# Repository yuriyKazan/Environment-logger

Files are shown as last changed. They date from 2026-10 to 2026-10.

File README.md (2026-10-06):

# Environment Logger

An autonomous ESP32-S3 telemetry logger: it reads temperature, humidity and pressure from a BME280 every 5 seconds, stamps each reading with a DS3231 real-time clock, 
prints a formatted line over UART, publishes the values over MQTT, and keeps running when the I2C bus misbehaves or a task hangs.

```
[14:18:54] T:24.3 H:40% P:983 ERR:0
```

> Author: **Yurii Kazan** · Course final project, Embedded Development · Firmware: C++ on ESP-IDF 5.5.3 + FreeRTOS

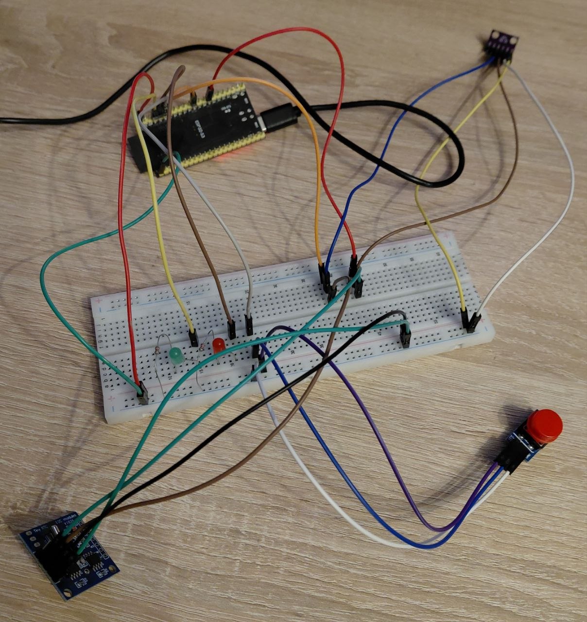
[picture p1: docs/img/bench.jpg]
Test bench


## Table of contents

1. [Project description](#1-project-description)
2. [Features](#2-features)
3. [Hardware and wiring](#3-hardware-and-wiring)
4. [Why these components](#4-why-these-components)
5. [Architecture](#5-architecture)
6. [Interfaces](#6-interfaces)
7. [Log format](#7-log-format)
8. [MQTT telemetry](#8-mqtt-telemetry)
9. [Error strategy](#9-error-strategy)
10. [How to build and run](#10-how-to-build-and-run)
11. [Results](#11-results)
12. [Testing](#12-testing)
13. [Known issues and limitations](#13-known-issues-and-limitations)
14. [What I would improve](#14-what-i-would-improve)
15. [Self-check against the checklist](#15-self-check-against-the-checklist)
16. [Technology stack, credits and license](#16-technology-stack-credits-and-license)

## 1. Project description

**Problem.** A logger that sits unattended must keep producing trustworthy data. The usual failure modes are quiet ones: a loose wire makes the I2C bus hang, a task 
deadlocks, the clock battery dies and every record is stamped `2000-01-01`. A logger that stops without telling anyone is worse than no logger.

**Solution.** The firmware is split into independent FreeRTOS tasks (sensor, UART output, supervisor, MQTT). The measurement is an event-driven state machine with 
bounded retries, every wait has a timeout, the I2C bus is protected by one mutex, and a task watchdog resets the chip if a task stops running. After a reset the 
firmware reports why it restarted.

**Use cases.** Room or lab climate logging, a data source for a dashboard, and a small reference for building recoverable I2C firmware on ESP-IDF.

## 2. Features

- BME280 readings (temperature, humidity, pressure) every 5 s, filtered with an EMA (`alpha` = 0.2).
- Timestamps from a DS3231 RTC; an invalid RTC (dead battery, default date) is detected and the entry is marked `!TIME`.
- Formatted log line over UART0 at 115200 baud, written by a single task.
- Best-effort MQTT publishing over Wi-Fi to a public broker; the logger works without a network.
- I2C error handling: three attempts 100 ms apart, then a bus reset requested from the supervisor, then the next cycle starts normally.
- Task watchdog (10 s, resets the chip) on the three tasks that keep the logger alive; the reset reason is logged at boot.
- No `delay()`, no `vTaskDelay()`, no busy-wait: pauses are states of a state machine, ended by events or one-shot timers.
- Two LEDs (OK heartbeat, error) and a button (short press clears the error counter, long press demonstrates the watchdog).
- A diagnostics task that periodically reports heap, CPU load and per-task stack use.
- Unit tests for the pure logic, run on the PC.

## 3. Hardware and wiring

Board: ESP32-S3-DevKitM-1, powered over USB.

| Part | Role | Interface | Address / pin |
|---|---|---|---|
| BME280 module | Temperature, humidity, pressure | I2C | `0x76` |
| DS3231 module (with CR2032) | Real-time clock | I2C, same bus | `0x68` (its EEPROM answers at `0x50`, unused) |
| LED_OK + 220 Ω | Heartbeat: T3 is alive | GPIO out | GPIO4 |
| LED_ERR + 220 Ω | Error / recovery in progress | GPIO out | GPIO5 |
| Button module (3 pins) | Operator input | GPIO in + interrupt | GPIO6, pressed = high |
| UART0 | Log output | UART | TX GPIO43, RX GPIO44, 115200 8N1 |

I2C: SDA = GPIO8, SCL = GPIO9, 400 kHz. The pull-ups are on the modules (BME280 10 kΩ, DS3231 4.7 kΩ per line, about 3.2 kΩ in parallel), so no external resistors are used.

```
ESP32-S3                BME280 (0x76)         DS3231 (0x68)
3V3  ------------------ VCC ----------------- VCC
GND  ------------------ GND ----------------- GND
GPIO8 (SDA) ------------ SDA ----------------- SDA
GPIO9 (SCL) ------------ SCL ----------------- SCL

GPIO4 --[220R]--|>|-- GND   (LED_OK)
GPIO5 --[220R]--|>|-- GND   (LED_ERR)
GPIO6 ------------------ OUT  (button module: VCC to 3V3, GND to GND, pressed = high)
```

Schematic: [`docs/schematic/schematic.png`](docs/schematic/schematic.png) ([PDF](docs/schematic/schematic.pdf)), KiCad sources in [`hardware/kicad/`](hardware/kicad/). 
More wiring notes: [`docs/hardware.md`](docs/hardware.md).

Notes:

- The DS3231 module has a charging circuit meant for a rechargeable LIR2032. This build uses a non-rechargeable CR2032, which is acceptable for a short demo; for long unattended use fit an LIR2032 or disable the charging circuit on the module.
- Wi-Fi: the ESP32-S3 supports **2.4 GHz networks only**.

## 4. Why these components

Each element answers one need of the project; nothing was added only to tick a checklist line.

| Element | Need it covers |
|---|---|
| BME280 | The measured quantities themselves, three in one chip on one I2C address |
| DS3231 | A log without a trustworthy time is hard to use; the DS3231 keeps time across power loss and flags a lost oscillator |
| One I2C bus for both | Two devices, two wires, one mutex; a second bus would add pins and no benefit |
| LED_OK / LED_ERR | The state of the logger is visible without a terminal |
| Button | A way to clear the error counter and to trigger the watchdog demonstration on demand |
| Wi-Fi + MQTT | Remote access to the readings; best effort, so it cannot endanger the logging |
| Task WDT | A hung task must end in a restart, not in silence |

Deliberately **not** included, with the reasons:

- **Photoresistor / ADC (checklist 2.1):** a temperature, humidity and pressure logger has no organic need for light measurement. It was in the original brief; I dropped it after discussing it with the instructor, because adding a sensor only to cover a checklist item would make the design less coherent. The log format therefore has no `LUX` field.
- **Light Sleep:** the board is powered over USB, so saving energy has no practical meaning here, and Light Sleep conflicts with the continuous Wi-Fi/MQTT link and with the UART log. See [`docs/decisions.md`](docs/decisions.md), item 10.
- **DMA:** one cycle moves about 20 bytes over I2C and the bus is busy 0.035 % of the time; measured, DMA would gain nothing ([`docs/measurements.md`](docs/measurements.md)).
- **Checklist 6.2 and 7.2-7.7:** not applicable to this design; the reason for each item is in [`docs/self-check.md`](docs/self-check.md) (summary in [section 15](#15-self-check-against-the-checklist) of this README).

## 5. Architecture

### Layers

| Layer | Responsibility | Contents |
|---|---|---|
| **Periph** | Hardware init and raw access | `I2cBus`, `Bme280`, `Ds3231`, `Led`, `Button`, `WifiManager` |
| **Logic** | Data processing | `SensorTask` (T1), `Ema`, `sensor_validation`, `TimeSource`, `LogEntry`, `format_log_line` |
| **Transport / Output** | Emitting data | `UartLogTask` (T2), `MqttPublisher`, `MqttTask` (T4) |
| **Reliability** | Staying alive | `SupervisorTask` (T3), `I2cMutex`, `ErrorCounter`, watchdog, reset reason, `DiagnosticsTask` |

Source layout: `src/periph`, `src/logic`, `src/transport`, `src/reliability`; shared headers and all constants (`config.h`) in `include/`. Upper layers call lower ones, never the reverse.

### Tasks

| Task | Priority | Responsibility |
|---|---|---|
| **T3 supervisor** | 6 | Bus reset on request, LEDs, button gestures, watchdog feed |
| **T1 sensor** | 5 | Measurement state machine: timer events, BME280 + DS3231 reads under the mutex, retries, validation, EMA, fan-out of the `LogEntry` |
| **T2 uart_log** | 4 | The only writer of log lines |
| **T4 mqtt** | 3 | Publish to the broker, best effort |
| diag | 1 | Periodic heap / CPU / stack snapshot |

Why Tasks and not one loop: the responsibilities are independent and have different timing needs, and a blocking call in one (an I2C transfer, a network publish) must block only that task. Why T4 is separate from T2: a network publish has unpredictable latency and would distort the UART cadence. The supervisor has the highest priority so that a recovery can always run.

### Queues and mutex

An arrow between two tasks is a **Queue**; two code paths reaching one resource need a **Mutex**.

| Queue | From → to | Item | When full |
|---|---|---|---|
| T1 queue | timers, T3 → T1 | `IsrEvent` | event dropped and counted |
| T3 queue | T1, button ISR, timer → T3 | `IsrEvent` | event dropped and logged |
| Q_LOG | T1 → T2 | `LogEntry` | newest entry dropped and counted |
| Q_MQTT | T1 → T4 | `LogEntry` | oldest entry dropped (the broker gets fresh data) |

**One mutex for the whole I2C bus**, not one per device. It is taken with a 200 ms timeout (never `portMAX_DELAY`), held only during a transfer, and always released through an RAII guard (`I2cLockGuard`), also on error paths. There is a single lock, so no lock-ordering problem. ISRs use only `...FromISR` calls.

### Block diagram

```mermaid
flowchart LR
    subgraph HW[Hardware]
        BME[BME280 0x76]
        RTC[DS3231 0x68]
        BTN[Button module GPIO6]
        LEDS[LED_OK / LED_ERR]
        UART[UART0]
        WIFI[Wi-Fi and MQTT broker]
    end
    TMR[esp_timer callbacks] --> Q1[[T1 queue]]
    Q1 --> T1
    subgraph Tasks
        T1[T1 sensor]
        T2[T2 uart_log]
        T3[T3 supervisor]
        T4[T4 mqtt]
    end
    MTX{{I2C_MUTEX}}
    T1 -- take/give --- MTX
    T3 -- take/give --- MTX
    MTX --- BME
    MTX --- RTC
    T1 --> QLOG[[Q_LOG]] --> T2 --> UART
    T1 --> QMQTT[[Q_MQTT]] --> T4 --> WIFI
    T1 -- I2cFailure, MeasurementOk --> Q3[[T3 queue]]
    BTN -- ISR --> Q3
    Q3 --> T3
    T3 -- RecoveryDone, TestHang --> Q1
    T3 --> LEDS
    T1 -. feeds .-> WDT((Task WDT))
    T2 -. feeds .-> WDT
    T3 -. feeds .-> WDT
```

### State machine of T1 (FSM)

```mermaid
stateDiagram-v2
    [*] --> Idle
    Idle --> WaitConversion: Tick, conversion started
    Idle --> WaitRetry: Tick, start failed (attempt below 3)
    WaitConversion --> Idle: read ok and sample plausible
    WaitConversion --> WaitRetry: read failed or sample rejected (attempt below 3)
    WaitConversion --> Recovery: read failed or sample rejected (attempt 3)
    WaitRetry --> WaitConversion: Retry timer, conversion started
    WaitRetry --> WaitRetry: Retry timer, start failed (attempt below 3)
    WaitRetry --> Recovery: Retry timer, start failed (attempt 3)
    Recovery --> Idle: RecoveryDone or RecoveryTimeout, failed cycle logged
```

The 10 ms BME280 conversion wait and the 100 ms retry gap are one-shot `esp_timer`s that post an event to T1's queue; T1 sleeps in `xQueueReceive` meanwhile.

### Sequence diagram: normal cycle

```mermaid
sequenceDiagram
    participant TMR as esp_timer
    participant T1 as T1 sensor
    participant MTX as I2C_MUTEX
    participant BME as BME280
    participant RTC as DS3231
    participant T2 as T2 uart_log
    participant T4 as T4 mqtt
    TMR->>T1: Tick (T1 queue)
    T1->>MTX: take (200 ms)
    T1->>BME: trigger forced conversion
    T1->>MTX: give
    Note over T1: one-shot timer of 10 ms, T1 waits on its queue (no delay)
    TMR->>T1: ConversionDone
    T1->>MTX: take (200 ms)
    T1->>BME: read status and data
    T1->>RTC: read time and status
    T1->>MTX: give
    Note over T1: validate, EMA, resolve the timestamp, build LogEntry
    T1->>T2: Q_LOG (LogEntry)
    T1->>T4: Q_MQTT (LogEntry)
    T2->>T2: format and print the line
    T4->>T4: publish when connected
```

### Sequence diagram: I2C failure and recovery

```mermaid
sequenceDiagram
    participant T1 as T1 sensor
    participant MTX as I2C_MUTEX
    participant BME as BME280
    participant T3 as T3 supervisor
    participant T2 as T2 uart_log
    loop attempts 1 to 3, 100 ms apart (one-shot timer)
        T1->>MTX: take
        T1->>BME: start or read
        BME--xT1: no answer
        T1->>MTX: give
    end
    T1->>T3: I2cFailure (T3 queue)
    Note over T1: state Recovery, waits at most 2 s
    T3->>T3: LED_ERR on, LED_OK off
    T3->>MTX: take (200 ms)
    T3->>T3: i2c_master_bus_reset (clears the bus)
    T3->>MTX: give
    T3-->>T1: RecoveryDone (T1 queue)
    T1->>T2: Q_LOG (ERR + 1, !SENS !TIME)
    Note over T1: next cycle starts normally at the next tick
    T1->>T3: MeasurementOk (when a cycle succeeds again)
    T3->>T3: LED_ERR off, LED_OK blinks again
```

### UML class view

The class diagram (tasks, drivers, mutex, data types and their dependencies) and the watchdog sequence diagram are in section 11 of [`docs/architecture.md`](docs/architecture.md); the rest of that document describes every design choice in full. The design decisions in "I chose X because Y; the alternative was Z" form are in [`docs/decisions.md`](docs/decisions.md).

## 6. Interfaces

| Interface | Configuration | Notes |
|---|---|---|
| **I2C** | `driver/i2c_master.h` (new driver), port 0, SDA 8 / SCL 9, 400 kHz, glitch filter 7 | Device handles at `0x76` and `0x68`; transfers have a 100 ms timeout; `i2c_master_bus_reset()` for recovery. `i2c_master_probe()` always runs at 100 kHz (fixed by ESP-IDF) |
| **UART** | UART0, 115200 8N1, TX 43 / RX 44 | The console; only T2 writes log lines |
| **Timers** | `esp_timer`: 5 s measurement tick, 10 ms conversion, 100 ms retry, 2 s recovery timeout, 3 s long press, 30 s Wi-Fi retry | All one-shot or periodic callbacks that only post events |
| **GPIO / interrupt** | Button any-edge ISR, quiet-time debounce 50 ms | The ISR only calls `xQueueSendFromISR` |
| **Task WDT** | 10 s, panic on timeout, T1 + T2 + T3 subscribed | See section 9 |
| **Wi-Fi / MQTT** | Station mode, `esp-mqtt`, QoS 0 | See section 8 |

All numeric constants (pins, intervals, timeouts, queue lengths, priorities, stack sizes) are in [`include/config.h`](include/config.h).

## 7. Log format

```
[HH:MM:SS] T:23.4 H:48% P:1013 ERR:0
```

- `T` temperature in °C, `H` relative humidity in %, `P` pressure in hPa, all EMA-filtered.
- `ERR` is the number of failed measurement cycles since boot or since the last short button press (saturating counter).
- Markers: ` !TIME` the timestamp does not come from a valid RTC (the internal clock is used); ` !SENS` the values are not from a successful read.

**EMA:** `filtered = alpha * raw + (1 - alpha) * filtered`, `alpha` = 0.2. At a 5 s period this is a time constant of 22 s: a short disturbance is attenuated to about half or two thirds, a single outlier passes with only 20 % of its size, and the filter follows a real change in about a minute. 0.05 reacted to only a quarter of a disturbance and was still 4.3 %RH off two minutes later; 0.5 hardly filtered. The experiment, with its limits, is in [`docs/ema-experiment.md`](docs/ema-experiment.md).

**Validation:** a sample outside the BME280 operating range (-40...85 °C, 0...100 %RH, 300...1100 hPa) or not finite is rejected and counted as a failed attempt; the filter only receives plausible samples. The RTC time is checked (oscillator-stop flag, date not `2000-01-01`, fields in range) before it is used.

Real log excerpts: [`docs/logs/`](docs/logs/).

## 8. MQTT telemetry

- Broker: `broker.hivemq.com` (public, port 1883), QoS 0, no retain.
- Topics: `envlogger/ykazan/temp`, `.../hum`, `.../pres` (published only when the sensor data is valid, so stale values never look fresh) and `.../err` (always).
- Watch it from any machine:

```
mosquitto_sub -h broker.hivemq.com -t "envlogger/ykazan/#" -v
```

- **Security note:** the broker is public and has no authentication. Anyone can read or publish to these topics; the topic prefix only avoids collisions and is not protection. Room climate data is harmless, but do not reuse this setup for anything sensitive.
- The MQTT path is **best effort and outside the I2C + WDT reliability guarantees**: T4 holds no mutex, never touches I2C, is not subscribed to the watchdog, and drops entries when the broker is not connected. During a router outage the UART log kept its 5 s cadence ([`docs/logs/phase3-mqtt.txt`](docs/logs/phase3-mqtt.txt)).
- Wi-Fi reconnect: 5 immediate attempts, then one attempt every 30 s without a limit, so the logger returns to the network when the access point does.

## 9. Error strategy

| Failure | What happens | Evidence |
|---|---|---|
| BME280 does not answer | 3 attempts 100 ms apart, then a bus reset by T3; the failed cycle is logged with `ERR` + 1 and `!SENS !TIME`; LED_ERR on; recovers by itself | [`phase4-i2c-recovery.txt`](docs/logs/phase4-i2c-recovery.txt), [`logic-analyzer.md`](docs/logic-analyzer.md) |
| A task hangs | The watchdog names it and resets the chip; the reset reason is logged after the restart | [`phase4-wdt.txt`](docs/logs/phase4-wdt.txt) |
| RTC time invalid | Internal clock is used, `!TIME` in the log | [`phase3-rtc.txt`](docs/logs/phase3-rtc.txt) |
| Wi-Fi or broker lost | T4 drops entries, UART log unaffected, automatic reconnect | [`phase3-mqtt.txt`](docs/logs/phase3-mqtt.txt) |
| Implausible sensor value | Rejected, counted as a failed attempt | unit tests |
| A consumer stalls (queue full) | Documented drop policy per queue, T1 never blocks | [`phase6-queue-overflow.txt`](docs/logs/phase6-queue-overflow.txt) |

Example of a failed cycle (the SDA wire was pulled out while running):

```
W (65460) T1: BME280 start failed: ESP_ERR_INVALID_STATE (attempt 1/3)
W (65560) T1: BME280 start failed: ESP_ERR_INVALID_STATE (attempt 2/3)
W (65660) T1: BME280 start failed: ESP_ERR_INVALID_STATE (attempt 3/3)
E (65660) T1: I2C failed 3 times in a row: requesting a bus reset
W (65670) T3: bus reset #1: ESP_OK
[17:27:36] T:24.5 H:40% P:982 ERR:1 !TIME !SENS
...
I (95470) T1: sensor is back
```

**Watchdog.** The timeout is 10 s with `CONFIG_ESP_TASK_WDT_PANIC=y`, so a timeout resets the chip and `ESP_RST_TASK_WDT` becomes visible after the restart. The course documents set both the WDT timeout and the measurement interval to 5 s, which would reset the logger on a normal cycle; here the feed is decoupled from the interval (T1 and T2 feed after each 1 s queue wait, T3 after each 0.5 s) and the worst case between two feeds of T1 is about 1.6 s. T4, the diagnostics task and the idle tasks are not subscribed, so a bad network can never reset the logger. Boot log after a watchdog reset:

```
E (26460) task_wdt: The following tasks/users did not reset the watchdog in time:
E (26460) task_wdt:  - T1_sensor (CPU 0)
...
E (405) reset: previous run ended with a WATCHDOG reset (task watchdog): a task hung or deadlocked
```

Defensive-coding review (every wait has a timeout, every retry is bounded, every return value is checked, how each shared object is protected): [`docs/defensive-review.md`](docs/defensive-review.md).

## 10. How to build and run

**Requirements:** PlatformIO (CLI or the VS Code extension), a USB cable, the wired board from section 3. The platform is pinned in `platformio.ini`: `espressif32@6.13.0`, which ships ESP-IDF 5.5.3.

```
git clone <repository URL>
cd Environment-logger

# Wi-Fi and MQTT credentials (git-ignored)
cp include/secrets.h.example include/secrets.h     # then edit SSID, password, broker URI

pio run                          # build
pio run -t upload                # flash
pio device monitor               # 115200 baud, with timestamps and exception decoder
pio test -e native               # unit tests on the PC, no board needed
```

Without Wi-Fi the logger still runs; T4 only reports that it cannot connect. A DS3231 with a dead battery reports `2000-01-01`; to set it once from the build time, enable `RTC_SET_FROM_BUILD_TIME_IF_INVALID` in `config.h`, flash, then disable it again.

**Before a demo, check `include/config.h`:**

- `FAULT_STALL_UART` must be `false`. When it is `true`, T2 deliberately stops printing for 90 s after three entries (this is the queue-overflow test).
- `DIAG_ENABLED` can be set to `false` if the extra snapshot line per minute is not wanted.

**What to see on the board:** LED_OK blinks at 1 Hz (T3 is alive); LED_ERR lights up while a bus failure is being handled. Short button press: `ERR` returns to 0. Long press (3 s): T1 hangs on purpose and the watchdog resets the chip about 10 s later.

## 11. Results

All numbers were measured on the real board (ESP32-S3-DevKitM-1, ESP-IDF 5.5.3, one measurement per 5 s); details in [`docs/measurements.md`](docs/measurements.md).

| Quantity | Value |
|---|---|
| Measurement cycle, tick to published entry | 11.9 / 12.0 / 12.4 ms (min / avg / max over 12 cycles; over 10 h 11.9-13.5 ms, one outlier of 21.6 ms in another run), of which 10 ms is the sensor conversion wait |
| I2C bus busy per cycle | about 1.8 ms of 5000 ms (0.035 %) |
| CPU load | 0.7 % |
| Free heap | 231.5-235.5 KB; lowest ever 226.9 KB after 10 h (230.6 KB at 60 s); free heap shows no downward trend |
| Failed cycle (3 attempts + reset) | about 220 ms, the UART log keeps its 5 s cadence |
| Stack, largest use of a 4096 B stack (10 h minimum of free stack) | `diag`: 2512 B used, 1584 B free; T1: 2300 B used, 1796 B free |
| Longest run | 10 h 18 min without a reset: 7425 log lines, all `ERR:0`, no `!SENS` / `!TIME` ([`phase7-long-run.txt`](docs/logs/phase7-long-run.txt)) |
| Unit tests | 37, all on the PC |

Cross-check with a logic analyzer ([`docs/logic-analyzer.md`](docs/logic-analyzer.md)): the cycles start 4.99974 s apart, the conversion wait on the wire is 10.26 ms, the read phase is 1.27 ms (firmware: 1.23 ms), the scan finds exactly `0x50`, `0x68` and `0x76`, and with SDA disconnected the three attempts are 107.5 ms apart.

The long run also had two MQTT disconnects (10.3 s and 15.2 s), both recovered automatically while the UART log kept running. The raw capture is not committed; the evidence file is produced from it by `tools/summarize_long_run.py` with SSID, IP and MAC replaced.

## 12. Testing

| Scenario | How | Result |
|---|---|---|
| Normal operation | 5+ minute run | `ERR:0`, 5 s cadence ([`phase3-pipeline.txt`](docs/logs/phase3-pipeline.txt)) |
| Long run | 10 h 18 min, nobody touching the board | no reset, `ERR:0` throughout, flat heap ([`phase7-long-run.txt`](docs/logs/phase7-long-run.txt)) |
| I2C failure and recovery | SDA wire pulled out and plugged back | 3 attempts, bus reset, automatic recovery ([`phase4-i2c-recovery.txt`](docs/logs/phase4-i2c-recovery.txt)) |
| Watchdog | Long button press | Chip reset, task named, reset reason logged ([`phase4-wdt.txt`](docs/logs/phase4-wdt.txt)) |
| RTC invalid | DS3231 never set (oscillator-stop flag set) | `!TIME` ([`phase3-rtc.txt`](docs/logs/phase3-rtc.txt)) |
| Button | Short and long presses | ([`phase4-button.txt`](docs/logs/phase4-button.txt)) |
| Wi-Fi / MQTT loss | Router switched off | UART cadence unaffected ([`phase3-mqtt.txt`](docs/logs/phase3-mqtt.txt)) |
| Queue overflow | `FAULT_STALL_UART` | Drops counted, T1 not blocked ([`phase6-queue-overflow.txt`](docs/logs/phase6-queue-overflow.txt)) |
| Pure logic | `pio test -e native` | EMA, error counter, log format, validation, timing statistics |

Logs are excerpts; private data (SSID, IP, MAC) is replaced with placeholders.

## 13. Known issues and limitations

- A button tap shorter than the 50 ms debounce quiet time loses its release event; the long-press timer then counts it as a short press after 3 s.
- A bus reset cannot revive a device that is permanently dead or unpowered; every cycle is then logged as failed until it answers. This applies only to a device that failed after a successful start.
- If the BME280 or DS3231 is missing or does not initialise at power-on, the boot self-check logs an error and `app_main` returns: no tasks start, so there is no retry, no LED_ERR and no watchdog. The board stays silent until it is reset or power-cycled with the device connected.
- The DS3231 charging circuit is meant for a rechargeable LIR2032, but a non-rechargeable CR2032 is fitted (section 3). A non-rechargeable cell should not be charged: fine for a short demo, not for long unattended use.
- The public MQTT broker has no authentication and no delivery guarantee (QoS 0); entries are dropped while disconnected.
- 2.4 GHz Wi-Fi only.
- The SCL pulses of the bus reset were not individually confirmed on the logic analyzer (the decoder merges them into the last NAK frame).
- The long run is one 10-hour capture on USB power in one room; it is not a temperature-cycling or brown-out test.
- `sys_evt` (an ESP-IDF task that runs the Wi-Fi event handler) has only 576 B of stack free; it is the one to watch if more work is added to the Wi-Fi/MQTT callbacks.

## 14. What I would improve

- Authenticated MQTT over TLS with a private broker, plus the minimal static web page (MQTT over WebSockets and Chart.js) as a live dashboard.
- Persist the log (flash or SD card) so that a Wi-Fi outage loses no data.
- Light Sleep or Deep Sleep for a battery-powered version, with the UART and Wi-Fi handled around the sleep.
- A hardware I2C bus-recovery path that can also power-cycle the sensors through a GPIO-switched supply.
- Time synchronisation of the RTC over SNTP when the network is available.
- A soak test across temperature changes and with a deliberately unstable power supply.

## 15. Self-check against the checklist

The course checklist was filled in with a piece of evidence (code, log or measurement) for every ticked item; items that do not fit this project are left unticked with a reason instead of being forced. Current state: **30 of 42 items ticked (71 %)**; the four demonstration items are ticked at the live defence (34 of 42, 81 %), and the other eight (2.1, 6.2, 7.2-7.7) are deliberately not applicable, each with its reason. Details and the "need it covers" column: [`docs/self-check.md`](docs/self-check.md).

## 16. Technology stack, credits and license

- C++17 firmware, ESP-IDF 5.5.3 (`framework = espidf`), FreeRTOS, PlatformIO with `espressif32@6.13.0`; Unity for the unit tests.
- Python (`tools/analyze_i2c.py`, `tools/plot_ema.py`) for the logic-analyzer and EMA analysis; Saleae Logic 2 for the captures; KiCad for the schematic; Mermaid for the diagrams.
- Wi-Fi/MQTT code is reused and adapted from my earlier course project (module5). BME280 and DS3231 drivers are my own, with the BME280 compensation formulas taken from the datasheet.
- Parts of this README were drafted with AI assistance from the project's own documents and logs, and then reviewed and corrected by the author.
- License: [MIT](LICENSE).

**Author:** Yurii Kazan

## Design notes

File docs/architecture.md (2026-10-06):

# Architecture

This document describes the firmware as it is implemented. Every constant mentioned here lives in `include/config.h`. Evidence for the behaviour described (logs, measurements) is linked from the sections below and listed in [`logs/`](logs/).

## 1. Layers

| Layer | Responsibility | Contents |
|---|---|---|
| **Periph** | Hardware init and raw access | `I2cBus`, `Bme280`, `Ds3231`, `Led`, `Button`, `WifiManager` |
| **Logic** | Data processing | `SensorTask` (T1), `Ema`, `sensor_validation`, `TimeSource`, `LogEntry`, `format_log_line` |
| **Transport / Output** | Emitting data | `UartLogTask` (T2), `MqttPublisher`, `MqttTask` (T4) |
| **Reliability** | Staying alive | `SupervisorTask` (T3), `I2cMutex`, `ErrorCounter`, `watchdog.h`, `reset_reason`, `DiagnosticsTask`, `TimingStats` |

Source layout mirrors this: `src/periph`, `src/logic`, `src/transport`, `src/reliability`, shared headers in `include/`. All constants (pins, intervals, timeouts, queue lengths, priorities) are in `include/config.h`; shared data types are in `include/data_types.h`. The code is C++; the pure logic that does not need ESP-IDF (`Ema`, `ErrorCounter`, `TimingStats`, `sensor_validation`, `format_log_line`) is unit-tested on the PC (`pio test -e native`, 37 tests).

Dependency rule: upper layers call lower ones, never the reverse. Tasks live in the layer whose responsibility they implement and are created from `app_main`.

## 2. Tasks (one responsibility per Task)

| Task | Layer | Priority | Responsibility |
|---|---|---|---|
| **T3 supervisor** | Reliability | 6 | Bus reset on request, LED_ERR / LED_OK, button gestures, watchdog feed |
| **T1 sensor** | Periph + Logic | 5 | Measurement state machine: timer events, BME280 + DS3231 reads under the I2C mutex, retries, validation, EMA, `LogEntry` fan-out |
| **T2 uart_log** | Transport | 4 | The only writer of log lines: receive `LogEntry`, format, print |
| **T4 mqtt** | Transport | 3 | Publish `LogEntry` to the MQTT broker, best effort |
| diag | Reliability | 1 | Periodic snapshot of heap, CPU load, per-task stack and state (not subscribed to the watchdog) |

The supervisor has the highest priority so that the recovery can always run, even while T1 is busy. T4 has the lowest application priority: it must never compete with the tasks that keep the logger alive.

Why Tasks and not one loop: the processes are independent, have different timing needs, and a blocking call in one (an I2C transfer, a network publish) must put only that Task into the Blocked state, not the whole system.

Why T4 is separate from T2: a network publish has an unpredictable and much longer latency than a UART write. Calling it from T2 would distort the UART log cadence. T4 holds no mutex, never touches I2C, is not subscribed to the watchdog, and is not part of the I2C + WDT reliability guarantees. The system works without Wi-Fi (see [`logs/phase3-mqtt.txt`](logs/phase3-mqtt.txt)).

## 3. Queues and mutex

Rule of thumb: an arrow between two Tasks is a Queue; two code paths reaching one resource need a Mutex.

| Queue | Producers | Consumer | Item | Length | When full |
|---|---|---|---|---|---|
| **T1 queue** | `esp_timer` callbacks (tick, conversion done, retry, recovery timeout), T3 | T1 | `IsrEvent` | 8 | the event is dropped and counted (T1 is never blocked) |
| **T3 queue** | T1, the button ISR, the long-press timer | T3 | `IsrEvent` | 8 | the event is dropped and logged |
| **Q_LOG** | T1 | T2 | `LogEntry` | 8 | the **newest** entry is dropped and counted |
| **Q_MQTT** | T1 | T4 | `LogEntry` | 4 | the **oldest** entry is dropped, so the broker gets the freshest data |

Events carried by the two event queues (`IsrEventType` in `data_types.h`):

| Queue | Event types |
|---|---|
| T1 queue | `Tick`, `ConversionDone`, `Retry`, `RecoveryDone`, `RecoveryTimeout`, `TestHang` |
| T3 queue | `I2cFailure`, `MeasurementOk`, `Button`, `ButtonRelease`, `LongPressTimeout` |

A FreeRTOS queue has one consumer, so T1's fan-out is two sends (Q_LOG and Q_MQTT) with zero timeout. The overflow policy for Q_LOG was verified with a fault-injection test ([`logs/phase6-queue-overflow.txt`](logs/phase6-queue-overflow.txt)).

**One mutex for the whole I2C bus** (`I2cMutex`, created with `xSemaphoreCreateMutex()` for priority inheritance), not one per device: the BME280 and the DS3231 share the bus, and T1 (reads) and T3 (bus reset) both reach it. It is always taken through `I2cLockGuard`, which gives it back on every exit path.

Rules:

- taken with a finite timeout, `I2C_MUTEX_TIMEOUT_MS` = 200 ms; `portMAX_DELAY` is never used on the mutex;
- held only during an I2C transaction, never across a conversion wait, a retry or a recovery;
- a single lock, so there is no lock-ordering problem and no nested locking;
- ISRs use only `...FromISR` APIs (`xQueueSendFromISR`) and never take a mutex.

The shared state and how each part is protected is listed in [`defensive-review.md`](defensive-review.md).

## 4. No `delay()`, and the state machine of T1

Pauses are states exited by an event, not blocking waits: no `delay`, no `vTaskDelay`, no busy-wait in the logic. Every wait is a queue wait with a finite timeout or a one-shot `esp_timer`.

T1 state machine:

```mermaid
stateDiagram-v2
    [*] --> Idle
    Idle --> WaitConversion: Tick, conversion started
    Idle --> WaitRetry: Tick, start failed (attempt below 3)
    WaitConversion --> Idle: read ok and sample plausible
    WaitConversion --> WaitRetry: read failed or sample rejected (attempt below 3)
    WaitConversion --> Recovery: read failed or sample rejected (attempt 3)
    WaitRetry --> WaitConversion: Retry timer, conversion started
    WaitRetry --> WaitRetry: Retry timer, start failed (attempt below 3)
    WaitRetry --> Recovery: Retry timer, start failed (attempt 3)
    Recovery --> Idle: RecoveryDone or RecoveryTimeout, failed cycle logged
```

- **Idle**: waits for `Tick` (one per `MEASURE_INTERVAL_MS` = 5 s).
- **WaitConversion**: the BME280 forced-mode conversion was started; a one-shot timer of `BME280_CONVERSION_US` = 10 ms posts `ConversionDone`.
- **WaitRetry**: an attempt failed; a one-shot timer of `I2C_RETRY_DELAY_MS` = 100 ms posts `Retry`. At most `I2C_MAX_ATTEMPTS` = 3 attempts per cycle.
- **Recovery**: the three attempts failed. T1 sends `I2cFailure` to T3 and waits for `RecoveryDone`, but not longer than `RECOVERY_TIMEOUT_MS` = 2 s.

A sample counts as an attempt failure in three cases: the I2C transfer fails, the BME280 reports a skipped measurement or a conversion still running, or the compensated values are outside the BME280 operating range (`validate_sample`, see section 6). A cycle that ends in Recovery is not retried again; it is logged as failed (`ERR` + 1, markers `!SENS` and `!TIME`) and the next cycle starts at the next tick. When a later cycle succeeds, T1 sends `MeasurementOk` to T3, which clears the error state.

Bounded retries and bounded waits keep the worst case small: a failed cycle takes about 220 ms and never blocks the UART log ([`logs/phase4-i2c-recovery.txt`](logs/phase4-i2c-recovery.txt)).

## 5. Supervisor, LEDs and the button (T3)

T3 reacts to events and also runs its own heartbeat: its queue wait times out every `SUPERVISOR_TICK_MS` = 500 ms, which toggles LED_OK (a 1 Hz blink shows that T3 is alive) and feeds the watchdog.

| Event or state | What T3 does |
|---|---|
| `I2cFailure` from T1 | LED_ERR on, LED_OK off; takes the I2C mutex (200 ms), calls `I2cBus::reset()`, answers `RecoveryDone` with the result, also when the reset failed |
| `MeasurementOk` from T1 | the sensor is back: LED_ERR off, LED_OK blinks again |
| short button press | clears the error counter (`ERR` in the log goes back to 0) |
| long button press (3 s) | watchdog demonstration: sends `TestHang` to T1, which blocks on purpose |

`I2cBus::reset()` calls `i2c_master_bus_reset()`. In ESP-IDF 5.5.3 this resets the I2C hardware state machine **and** clears the bus (SCL pulses until a slave releases SDA), and the device handles stay valid, so recreating the bus is not needed.

The button is a 3-pin module with an on-board pull-down: low at rest, high when pressed (`BUTTON_PRESSED_LEVEL` = 1). An any-edge ISR applies a quiet-time debounce (an edge counts only after `BUTTON_DEBOUNCE_US` = 50 ms without any edge) and posts `Button` or `ButtonRelease` to the T3 queue. A press starts a one-shot long-press timer (`BUTTON_LONG_PRESS_MS` = 3000 ms); a release before it expires is a short press, and the timer handler checks the pin level too, because a tap shorter than the debounce time loses its release event ([`logs/phase4-button.txt`](logs/phase4-button.txt)).

## 6. Watchdog

| Item | Value |
|---|---|
| Timeout | 10 s, `CONFIG_ESP_TASK_WDT_PANIC=y` (a timeout resets the chip) |
| Measurement interval | 5 s (independent of the timeout) |
| Subscribed tasks | T1, T2, T3 |
| Not subscribed | T4 (network), diag, the idle tasks |
| Feed | at the top of every loop iteration of each subscribed task, i.e. after each queue wait (1 s for T1 and T2, 0.5 s for T3) |

The course documents set both the timeout and the interval to 5 s, which would reset the system on a normal cycle. Here the feed is decoupled from the measurement interval, and the timeout is far longer than the longest legal pause: the worst case between two feeds of T1 is about 1.6 s (see [`defensive-review.md`](defensive-review.md)). A task that blocks anywhere else stops feeding, and the watchdog names it and resets the chip within 10 s ([`logs/phase4-wdt.txt`](logs/phase4-wdt.txt)).

At boot `esp_reset_reason()` is logged first; a watchdog reset is logged as an error; a panic, brownout or CPU lockup reset is logged as a warning; any other reason is logged as info. So a previous hang is visible after the restart.

## 7. Data structures, time and log format

```c
struct LogEntry {
    time_t   ts;         // from the DS3231 when valid, else the internal clock
    float    temp_c;     // EMA-filtered
    float    hum_pct;    // EMA-filtered
    float    press_hpa;  // EMA-filtered
    uint32_t err_cnt;    // failed measurement cycles, saturating
    uint8_t  flags;      // LOG_FLAG_SENSOR_VALID, LOG_FLAG_TIME_TRUSTED
};
```

Log line: `[HH:MM:SS] T:23.4 H:48% P:1013 ERR:0`, with two markers when needed: ` !TIME` (the timestamp does not come from a valid RTC) and ` !SENS` (the sensor values are not from a successful read). The `LUX` field of the assignment brief is absent because the photoresistor was dropped (see [`decisions.md`](decisions.md)).

**EMA filter:** `filtered = alpha * raw + (1 - alpha) * filtered`, `alpha` = 0.2. The choice is justified with real data in [`ema-experiment.md`](ema-experiment.md). The filter only receives samples that passed the plausibility check.

**Validation:** a sample is rejected, and counted as a failed attempt, when a value is not finite or outside the BME280 operating range (-40...85 C, 0...100 %RH, 300...1100 hPa).

**Time:** `TimeSource` synchronises the system clock from the DS3231 at boot. For every entry T1 reads the DS3231 under the same mutex as the BME280; a valid reading (oscillator-stop flag clear, date not the default 2000-01-01, fields in range) gives the timestamp. Otherwise the internal clock is used and the entry is marked `!TIME` ([`logs/phase3-rtc.txt`](logs/phase3-rtc.txt)).

**Error counter:** `ErrorCounter` is atomic and saturating (it stops at its maximum instead of wrapping to 0). T1 increments it once per failed cycle; a short button press resets it.

## 8. MQTT telemetry (T4)

- Topics: `envlogger/ykazan/temp`, `/hum`, `/pres` (only when the sensor data is valid, so stale values are never published as fresh) and `/err` (always); public broker `broker.hivemq.com`, QoS 0, no retain.
- A public broker means anyone can read or write the topics. Room climate data is harmless and the prefix is a uniqueness aid, not protection. This is a known limitation, listed in the README.
- T4 never blocks anything: when the broker is not connected the entries are dropped.
- Wi-Fi: `WifiManager` retries immediately 5 times after a drop, then once every 30 s (one-shot timer), without a limit, so the logger reconnects when the access point returns. The ESP32-S3 supports 2.4 GHz networks only. Credentials and the broker URI are in git-ignored `include/secrets.h` (template: `secrets.h.example`).
- Evidence: values received by an independent client, and a router outage during which the UART log kept its 5 s cadence ([`logs/phase3-mqtt.txt`](logs/phase3-mqtt.txt)).

## 9. Boot sequence

`app_main` runs, in this order: log the reset reason; create the I2C bus and scan it; initialise the BME280 and DS3231 and read the RTC state; synchronise the clock (`TimeSource`); create the mutex, the queues, the LEDs; start T2, then T1 (which creates its queue and timers), then T3 (given T1's queue), then attach the button ISR to the T3 queue; start the diagnostics task; last, best effort, NVS, Wi-Fi and MQTT. If the network part fails, the UART log keeps running.

## 10. Block diagram

```mermaid
flowchart LR
    subgraph HW[Hardware]
        BME[BME280 0x76]
        RTC[DS3231 0x68]
        BTN[Button module GPIO6]
        LEDS[LED_OK / LED_ERR]
        UART[UART0]
        WIFI[Wi-Fi and MQTT broker]
    end
    TMR[esp_timer callbacks] --> Q1[[T1 queue]]
    Q1 --> T1
    subgraph Tasks
        T1[T1 sensor]
        T2[T2 uart_log]
        T3[T3 supervisor]
        T4[T4 mqtt]
    end
    MTX{{I2C_MUTEX}}
    T1 -- take/give --- MTX
    T3 -- take/give --- MTX
    MTX --- BME
    MTX --- RTC
    T1 --> QLOG[[Q_LOG]] --> T2 --> UART
    T1 --> QMQTT[[Q_MQTT]] --> T4 --> WIFI
    T1 -- I2cFailure, MeasurementOk --> Q3[[T3 queue]]
    BTN -- ISR --> Q3
    Q3 --> T3
    T3 -- RecoveryDone, TestHang --> Q1
    T3 --> LEDS
    T1 -. feeds .-> WDT((Task WDT))
    T2 -. feeds .-> WDT
    T3 -. feeds .-> WDT
```

## 11. UML

### Class view

```mermaid
classDiagram
    class SensorTask { +start() }
    class SupervisorTask { +start() }
    class UartLogTask { +start() }
    class MqttTask { +start() }
    class DiagnosticsTask { +start() }
    class Bme280 { +init() +start_measurement() +read() }
    class Ds3231 { +init() +read() +set_time() }
    class I2cBus { +init() +reset() +probe() +scan() }
    class I2cMutex { +take(timeout) +give() }
    class I2cLockGuard
    class Led { +set() +toggle() }
    class Button { +init() +is_pressed() }
    class WifiManager { +init() +connected() }
    class MqttPublisher { +init() +start() +publish() }
    class Ema { +update(raw) }
    class TimeSource { +init() +resolve() }
    class ErrorCounter { +increment() +reset() +value() }
    class TimingStats { +add() +avg() }
    class LogEntry {
        +time_t ts
        +float temp_c
        +float hum_pct
        +float press_hpa
        +uint32_t err_cnt
        +uint8_t flags
    }
    SensorTask --> Bme280
    SensorTask --> Ds3231
    SensorTask --> Ema
    SensorTask --> TimeSource
    SensorTask --> ErrorCounter
    SensorTask --> TimingStats
    SensorTask --> I2cLockGuard
    SensorTask --> LogEntry : produces
    I2cLockGuard --> I2cMutex
    Bme280 --> I2cBus
    Ds3231 --> I2cBus
    SupervisorTask --> I2cBus : reset
    SupervisorTask --> I2cMutex
    SupervisorTask --> Led
    SupervisorTask --> Button
    SupervisorTask --> ErrorCounter
    UartLogTask --> LogEntry : consumes
    MqttTask --> MqttPublisher
    MqttTask --> LogEntry : consumes
    MqttPublisher --> WifiManager : started on IP
```

### Sequence 1: normal measurement cycle

```mermaid
sequenceDiagram
    participant TMR as esp_timer
    participant T1 as T1 sensor
    participant MTX as I2C_MUTEX
    participant BME as BME280
    participant RTC as DS3231
    participant T2 as T2 uart_log
    participant T4 as T4 mqtt
    TMR->>T1: Tick (T1 queue)
    T1->>MTX: take (200 ms)
    T1->>BME: trigger forced conversion
    T1->>MTX: give
    Note over T1: one-shot timer of 10 ms, T1 waits on its queue (no delay)
    TMR->>T1: ConversionDone
    T1->>MTX: take (200 ms)
    T1->>BME: read status and data
    T1->>RTC: read time and status
    T1->>MTX: give
    Note over T1: validate, EMA, resolve the timestamp, build LogEntry
    T1->>T2: Q_LOG (LogEntry)
    T1->>T4: Q_MQTT (LogEntry)
    T2->>T2: format and print the line
    T4->>T4: publish when connected
```

### Sequence 2: I2C failure and recovery

```mermaid
sequenceDiagram
    participant T1 as T1 sensor
    participant MTX as I2C_MUTEX
    participant BME as BME280
    participant T3 as T3 supervisor
    participant T2 as T2 uart_log
    loop attempts 1 to 3, 100 ms apart (one-shot timer)
        T1->>MTX: take
        T1->>BME: start or read
        BME--xT1: no answer
        T1->>MTX: give
    end
    T1->>T3: I2cFailure (T3 queue)
    Note over T1: state Recovery, waits at most 2 s
    T3->>T3: LED_ERR on, LED_OK off
    T3->>MTX: take (200 ms)
    T3->>T3: i2c_master_bus_reset (clears the bus)
    T3->>MTX: give
    T3-->>T1: RecoveryDone (T1 queue)
    T1->>T2: Q_LOG (ERR + 1, !SENS !TIME)
    Note over T1: next cycle starts normally at the next tick
    T1->>T3: MeasurementOk (when a cycle succeeds again)
    T3->>T3: LED_ERR off, LED_OK blinks again
```

### Sequence 3: watchdog demonstration (long button press)

```mermaid
sequenceDiagram
    participant U as User
    participant BTN as Button ISR
    participant T3 as T3 supervisor
    participant T1 as T1 sensor
    participant WDT as Task WDT
    U->>BTN: press and hold
    BTN->>T3: Button
    Note over T3: long-press timer, 3 s
    T3->>T1: TestHang
    T1->>T1: blocks on a semaphore that is never given
    Note over T1: no more feeding, T2 and T3 keep feeding
    WDT->>WDT: 10 s without a feed from T1
    WDT-->>T1: reset the chip (T1_sensor named in the message)
    Note over T1: after the restart the reset reason is logged
```

## 12. Resolved questions and known limitations

Questions that were open during the design and are now answered:

- BME280 conversion time: 9.3 ms worst case for oversampling x1 (datasheet), 10 ms used.
- Is `i2c_master_bus_reset()` enough for a stuck bus? Yes, it also clears the bus (SCL pulses) and keeps the device handles valid.
- The schematic is in `hardware/kicad/` and exported to `schematic/`.

Known limitations are listed in [`defensive-review.md`](defensive-review.md) (section 6) and in the README.

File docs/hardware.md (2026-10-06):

# Hardware: peripherals and GPIO map

Target: ESP32-S3 (`esp32-s3-devkitm-1`), ESP-IDF 5.5.3.

## Peripherals

| Peripheral | Role | Interface | Address / config |
|---|---|---|---|
| BME280 | Temperature, humidity, pressure | I2C | `0x76` |
| DS3231 RTC | Timestamp source | I2C (same bus) | `0x68` |
| UART0 | Formatted log output | UART | 115200 8N1 |
| LED_OK | System healthy indicator | GPIO out | via 220 Ω |
| LED_ERR | Error / recovery indicator | GPIO out | via 220 Ω |
| Button | Short press: clear the error counter. Long press (3 s): watchdog test | GPIO in + interrupt | 3-pin module (VCC, GND, OUT) with an on-board pull-down, pressed = high |
| Timer | Measurement tick | `esp_timer` | 5 s period |
| Task WDT | Hang detection | `esp_task_wdt` | see [architecture](architecture.md) |

No analog input: the photoresistor was intentionally dropped, because a temperature/humidity/pressure logger has no organic need for it (see [decisions](decisions.md)).

## GPIO map

| Signal | GPIO | Notes |
|---|---|---|
| I2C SDA | 8 | 400 kHz, shared by BME280 and DS3231 |
| I2C SCL | 9 | pull-ups are on the modules, no external resistors (see wiring notes) |
| UART0 TX | 43 | console / log output, 115200 baud |
| UART0 RX | 44 | default console RX (unused by the application) |
| LED_OK | 4 | active high, 220 Ω series resistor |
| LED_ERR | 5 | active high, 220 Ω series resistor |
| Button | 6 | module OUT pin; high while pressed, internal pull-down, any-edge interrupt with quiet-time debounce |

## Wiring

```
ESP32-S3                BME280 (0x76)         DS3231 (0x68)
3V3  ------------------ VCC ----------------- VCC
GND  ------------------ GND ----------------- GND
GPIO8 (SDA) ------------ SDA ----------------- SDA
GPIO9 (SCL) ------------ SCL ----------------- SCL

No external I2C pull-ups: they are already on the modules
(BME280: 10 kΩ per line, DS3231: 4.7 kΩ per line).

GPIO4 --[220R]--|>|-- GND   (LED_OK)
GPIO5 --[220R]--|>|-- GND   (LED_ERR)
GPIO6 ------------------ OUT  (button module: VCC to 3V3, GND to GND, pressed = high)
```

Notes:
- DS3231 needs a working backup battery. With a dead or missing battery it reports `2000-01-01 00:00:00`; the firmware must validate the timestamp before logging it.
- I2C pull-ups are provided by the modules (BME280 10 kΩ, DS3231 4.7 kΩ per line), giving about 3.2 kΩ per line in parallel, which is suitable for 400 kHz with short wires. Add external 4.7-10 kΩ pull-ups only if a different module set has none; do not stack extra pull-ups blindly. If 400 kHz is unstable, shorten the wires first, then fall back to 100 kHz.
- The DS3231 module has a charging circuit meant for a rechargeable LIR2032. This build uses a non-rechargeable CR2032, which is acceptable for a short demo; for long unattended use fit an LIR2032 or disable the charging circuit on the module.
- Schematic: KiCad source in `hardware/kicad/`, exported to `docs/schematic/schematic.pdf` and `schematic.png`.

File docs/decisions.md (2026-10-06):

# Design Decisions

Format: "I chose X because Y; the alternative was Z, but because of W...".

## 1. FreeRTOS instead of a superloop
I chose FreeRTOS (Tasks + Queue + Mutex) because BME280 polling, formatted UART output and WDT feeding are independent responsibilities with different waiting disciplines. The alternative was a superloop, but with a shared I2C bus and the need to keep a fault in one part from starving the WDT feeder, it scales worse.

## 2. Four layers
I chose Periph / Logic / Transport-Output / Reliability because this satisfies the "at least 3 layers" requirement and gives the WDT, error recovery and mutexes a place of their own. The alternative was three layers, but reliability code would then be spread across the other layers.

## 3. ESP-IDF instead of Arduino
I chose ESP-IDF 5.5.3 (`framework = espidf`) because the project needs direct access to `esp_task_wdt`, `esp_timer`, the new I2C master driver and the ESP-IDF Wi-Fi/MQTT stack. `gptimer` and light sleep are not used: one-shot and periodic `esp_timer`s are enough for the 5 s cadence, and light sleep was judged not worthwhile (item 10). The alternative was Arduino, but the course examples would have to be ported to the IDF API anyway.

## 4. `i2c_master` driver
I chose the new `driver/i2c_master.h` because the legacy `i2c_cmd_link` API is deprecated, and `i2c_master` is already used in my earlier projects (module5). The alternative was the legacy driver from the assignment brief, but it is no longer being developed.

## 5. No `delay()`
I chose event-driven waiting (Queue, Task Notification, timers) plus an FSM because it is a project rule. The alternative was `vTaskDelay`, but it hides the event-driven model and complicates WDT logic.

## 6. `portMAX_DELAY` and the WDT
Mutexes are always taken with a finite timeout (`pdMS_TO_TICKS(200)`); `portMAX_DELAY` is allowed only in tasks that do not feed the WDT, with an explanatory comment. The one deliberate exception is `SensorTask::test_hang()`, which blocks T1 forever on purpose to demonstrate the watchdog (long button press). The WDT timeout is chosen with margin and decoupled from the measurement interval (the course documents set both to 5 s, which is a documentation error).

## 7. README: the most informative variant
The README merges all section lists from the course documents instead of using the minimal set.

## 8. MQTT telemetry (Task 4) and web page are extensions
MQTT is a mandatory best-effort channel alongside UART (reusing `module5`); the web page is optional. Neither counts toward the I2C+WDT reliability criterion.

## 9. Task watchdog: 10 s, resets the chip, application tasks only
I chose a 10 s task WDT timeout with `CONFIG_ESP_TASK_WDT_PANIC=y`, fed about once per second by T1, T2 and T3 from their timed queue waits, because the timeout must be much longer than the longest legal pause in the system but short enough to catch a real hang, and it must be independent of the 5 s measurement interval (the course documents set both to 5 s, so a normal cycle could trigger a reset). Without `PANIC` a timeout only prints a warning and the chip never resets, so `ESP_RST_TASK_WDT` would never be seen. The idle tasks are not monitored, so a timeout always points at one of T1-T3; T4 (network) is deliberately not subscribed, so a bad Wi-Fi link can never reset the logger. The alternative, feeding the WDT from T3 based on heartbeats of the other tasks, has a single feed point but hides which task hung. The settings live in `sdkconfig.defaults`; the generated `sdkconfig.<env>` is not tracked.

## 10. No Light Sleep
I chose not to implement Light Sleep between measurements, because the board is powered over USB, so saving energy has no practical meaning for this setup, and my earlier project (module6) showed that UART output together with Light Sleep needs workarounds (the UART and the console can be cut or garbled around a sleep), which would put the main deliverable, the UART log, at risk. The alternative was to add `esp_light_sleep_start()` after each cycle, but it would also conflict with the continuous Wi-Fi/MQTT link and with the event-driven timers that the design is built on. No checklist item requires it (it is only mentioned in the course Q&A).

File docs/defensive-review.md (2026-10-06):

# Defensive coding review

Review of the firmware against the three defensive-coding rules from the course material:

1. check every returned value (return codes, byte counts);
2. bound every retry loop (never retry forever);
3. put a timeout on every blocking wait.

## 1. Every wait has a timeout

| Where | Wait | Timeout |
|---|---|---|
| T1 `SensorTask::run` | `xQueueReceive` on its event queue | 1000 ms (`TASK_WAIT_MS`), then the watchdog is fed |
| T2 `UartLogTask::run` | `xQueueReceive` on Q_LOG | 1000 ms |
| T3 `SupervisorTask::run` | `xQueueReceive` on its queue | 500 ms (`SUPERVISOR_TICK_MS`), then LED_OK toggles |
| T4 `MqttTask::run` | `xQueueReceive` on Q_MQTT | 1000 ms |
| I2C bus | `I2cMutex::take` (always through `I2cLockGuard`) | 200 ms (`I2C_MUTEX_TIMEOUT_MS`) |
| I2C transfers | `i2c_master_transmit` / `_transmit_receive` | 100 ms (`I2C_XFER_TIMEOUT_MS`) |
| I2C probe | `i2c_master_probe` | 50 ms (`I2C_PROBE_TIMEOUT_MS`) |
| T1 waiting for T3 | one-shot recovery timer | 2000 ms (`RECOVERY_TIMEOUT_MS`) |
| Queue sends | `xQueueSend` | 0 (never blocks; a full queue is counted or the oldest entry is dropped) |

The only unbounded wait in the code is `SensorTask::test_hang()` (`xSemaphoreTake(..., portMAX_DELAY)`). It runs only after a long button press and exists to demonstrate the watchdog: T1 stops feeding it on purpose. It is documented in the code and in `decisions.md`.

Worst case between two watchdog feeds of T1: the queue wait (1 s) plus the longest event handler. The longest handler is the read after a conversion: mutex (200 ms) and up to four I2C transfers (4 x 100 ms), about 0.6 s. So about 1.6 s against a 10 s watchdog timeout.

## 2. Every retry is bounded

| Retry | Bound |
|---|---|
| BME280 measurement | `I2C_MAX_ATTEMPTS` = 3 per cycle, 100 ms apart (one-shot timer), then one bus reset request |
| Bus reset | one per failed cycle; T1 waits at most 2 s for the answer; the next cycle starts normally |
| Wi-Fi reconnect | `WIFI_FAST_RETRIES` = 5 immediate attempts, then one attempt every 30 s. This is deliberately unbounded in count: a logger that runs for hours must reconnect when the access point returns. It is driven by a one-shot timer and never blocks or delays another task |
| MQTT reconnect | handled by the esp-mqtt stack; T4 only publishes while connected |

## 3. Return values

- All driver and task methods return `esp_err_t` (or a status enum) and every caller checks it: I2C drivers, `I2cBus`, `I2cMutex`, `Led`, `Button::init`, task and timer creation, queue creation, `WifiManager`, `MqttPublisher`.
- The I2C drivers do not trust the transfer alone: BME280 chip ID is verified (`0x60`), the "measuring" status bit and the "skipped measurement" marker are checked, and a sample outside the physical range is rejected before it reaches the filter (`sensor_validation.h`, unit-tested).
- DS3231 time is classified (oscillator-stop flag, default date 2000-01-01, out-of-range fields) and the log marks untrusted time (`!TIME`).
- Calls whose result is intentionally ignored are marked `(void)` with the reason next to them: stopping a timer that may not be running (`esp_timer_stop`), and removing one old entry from a full queue (`xQueueReceive` on Q_MQTT).
- A failed `init()` of the BME280 or DS3231 releases its I2C device handle, so the call can be repeated.
- Nothing is left to `ESP_ERROR_CHECK` (which would abort); failures are logged and, once the tasks are running, the system keeps going with the UART log as the last thing to stop. The exception is a failed boot self-check, see section 6.

## 4. Shared state

| Data | Writers and readers | Protection |
|---|---|---|
| I2C bus | T1 (measurements), T3 (bus reset); before the tasks start, `app_main` | one mutex for the whole bus; a single lock, so there is no lock-ordering problem |
| `ErrorCounter` | T1 increments, T3 resets | `std::atomic`, saturating |
| Queues (T1 queue, T3 queue, Q_LOG, Q_MQTT) | producers and one consumer each | FreeRTOS queues; the button ISR uses `xQueueSendFromISR` |
| LEDs | T3 only | single owner |
| `TimeSource` state | T1 only after start | single owner |
| Wi-Fi and MQTT "connected" flags | event loop writes, T4 reads | `std::atomic<bool>` |
| Button debounce state | the ISR only (`volatile`) | single writer |

ISR code uses only ISR-safe calls (`xQueueSendFromISR`, `esp_timer_get_time`, `gpio_get_level`) and never takes a mutex.

## 5. Failure behaviour (summary)

| Failure | What happens | Evidence |
|---|---|---|
| BME280 does not answer | 3 attempts, bus reset, failed cycle logged with `ERR` + 1 and `!SENS`, LED_ERR on; recovers by itself | `docs/logs/phase4-i2c-recovery.txt` |
| A task hangs | the watchdog names it and resets the chip; the reset reason is logged after the restart | `docs/logs/phase4-wdt.txt` |
| RTC time invalid | internal clock, `!TIME` in the log | `docs/logs/phase3-rtc.txt` |
| Wi-Fi or broker lost | T4 drops entries, UART log unaffected, reconnects by itself | `docs/logs/phase3-mqtt.txt` |
| Implausible sensor value | rejected, counted as a failed attempt | unit tests (`test_sensor_validation`) |

## 6. Known limitations

- A button tap shorter than the 50 ms debounce quiet time loses its release event; the long-press timer then counts it as a short press after 3 s.
- A bus reset cannot revive a device that is permanently dead or unpowered; the cycle is logged as failed every time until it answers again.
- If the BME280 or DS3231 is missing or does not initialise at power-on, the boot self-check logs an error and `app_main` returns: no tasks start, so there is no retry, no LED_ERR and no watchdog. The board stays silent until it is reset with the device connected. (A device that fails after a successful start is handled by the retry and bus-reset path.)
- Stack sizes (4096 bytes per task) were verified by measuring the high-water mark ([`measurements.md`](measurements.md), and over a 10 h run in [`logs/phase7-long-run.txt`](logs/phase7-long-run.txt)): the smallest free stack over the 10 h run was 1584 B (`diag`), 1796 B (T1), 1876 B (T2), 2000 B (T4) and 3156 B (T3). T3 uses only 940 B and could have a 2048 B stack.

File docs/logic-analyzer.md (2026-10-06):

# Logic analyzer captures

Captured with an 8-channel 24 MHz logic analyzer (a "Saleae clone") and Saleae Logic 2 with its I2C analyzer. Connections: Channel 0 to SDA (GPIO8), Channel 1 to SCL (GPIO9), GND to GND; Channel 2 is not connected. Raw exports of the decoded bus traffic are in [`img/logic-analyzer/`](img/logic-analyzer/) (`boot.csv`, `measurement.csv`, `nack-recovery.csv`); the numbers below come from `tools/analyze_i2c.py` run on those files.

## 1. Board start: address scan and BME280 initialisation

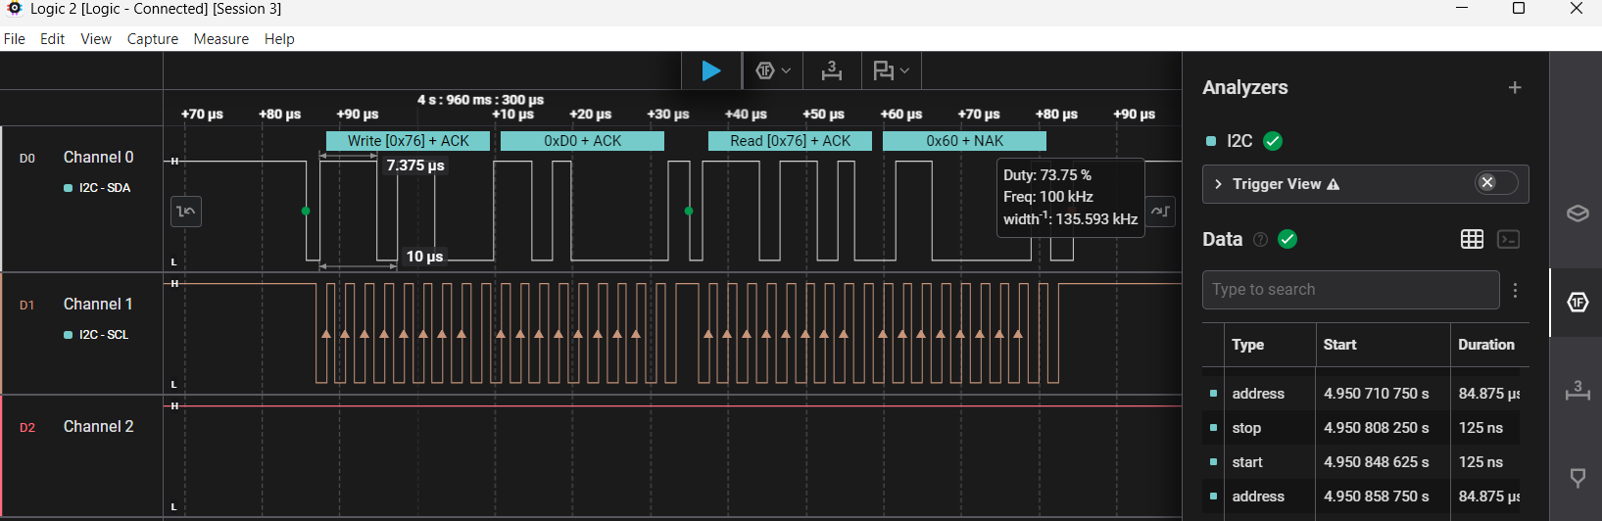
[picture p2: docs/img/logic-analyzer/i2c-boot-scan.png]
Chip ID read at start


The screenshot shows the BME280 chip ID read during initialisation, decoded by the analyzer: `Write [0x76] + ACK`, register `0xD0 + ACK`, `Read [0x76] + ACK`, data `0x60 + NAK` (the NAK after the last byte is how a master ends a read). `0x60` is the BME280 chip ID. The SCL pulses in this zoom are about 2.5 us apart, which is 400 kHz.

The address scan is quantified from `boot.csv`:

| Quantity | Value |
|---|---|
| Probed addresses | 112 (`0x08` to `0x77`), one address byte each |
| Answered with ACK | 3: `0x50` (EEPROM on the DS3231 module), `0x68` (DS3231), `0x76` (BME280) |
| Answered with NACK | 109 |
| Address byte duration | 84.9 us (the IDF probe always runs at 100 kHz) |
| Whole scan | 16.6 ms |

After the scan the firmware works at 400 kHz: the address byte of those transfers lasts 21.1 us, which is 4.02 times shorter than a probe, i.e. 400 kHz against 100 kHz. The initialisation then reads the chip ID (`0x60`), the 26 + 7 bytes of calibration data and writes `0xF5 = 0x00` and `0xF2 = 0x01`.

## 2. One measurement cycle

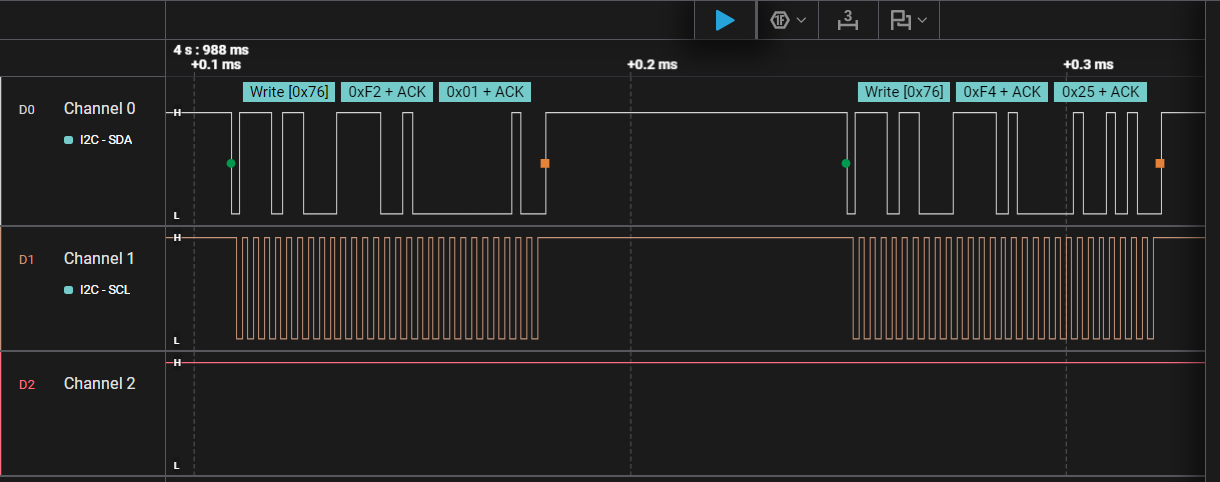
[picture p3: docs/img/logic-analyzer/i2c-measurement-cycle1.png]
Start of a conversion

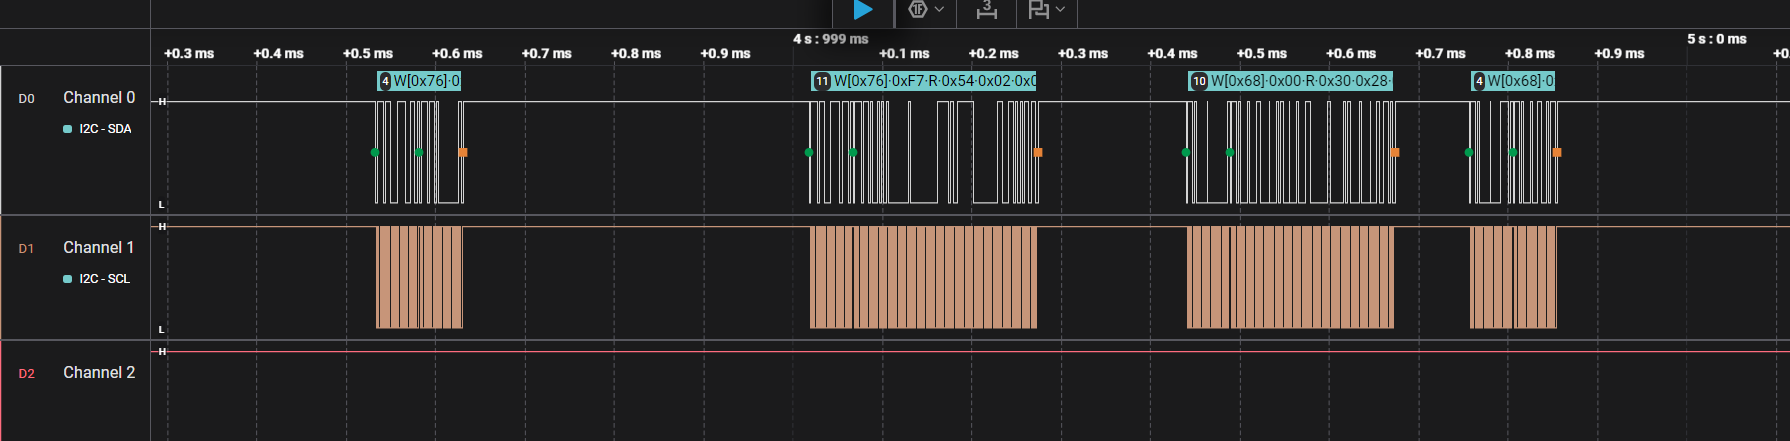
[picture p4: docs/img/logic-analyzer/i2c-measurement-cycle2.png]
Reading the results


The first screenshot shows the two writes that start a forced-mode conversion: `0xF2 = 0x01` (humidity oversampling x1) and `0xF4 = 0x25` (temperature and pressure x1, forced mode). The second shows the reads about 10 ms later: the BME280 status (`0xF3`), its 8 data bytes (`0xF7`...), the DS3231 time registers (7 bytes from `0x00`) and its status register (`0x0F`).

From `measurement.csv` (three consecutive cycles):

| Step | Bus time | Gap before it |
|---|---|---|
| Write `0xF2 0x01` to `0x76` | 72 us | |
| Write `0xF4 0x25` to `0x76` | 72 us | 69 us |
| Read BME280 status (1 byte) | 49 us | **10.26 ms** (the conversion wait) |
| Read BME280 data (8 bytes) | 207 us | 0.15 ms |
| Read DS3231 time (7 bytes) | 184 us | 0.21 ms |
| Read DS3231 status (1 byte) | 49 us | 0.13 ms |

- The cycles start 4.99974 s apart: the three bursts start at 4.988108 s, 9.987845 s and 14.987587 s on the analyzer clock, i.e. every 5 s as configured. The idle gap between the end of one burst and the start of the next is about 4.988 s (not the same quantity), because a burst itself lasts about 11.7 ms.
- The wait between the conversion start and the read is 10.26 ms: the 10 ms one-shot timer plus 0.26 ms of task latency. Nothing blocks during it.
- Data on the wire: 0.63 ms of actual transfers per cycle (0.013 % of the 5 s). The firmware measured 534 us for "start" and 1230 us for "read" ([`measurements.md`](measurements.md)); the wire time is only 144 us for the "start" writes (two writes, 72 us each) and 489 us for the four reads (49 + 207 + 184 + 49 us); the rest of the firmware figures, together with the gaps between the transfers, is driver and mutex overhead, and the read phase of 1.27 ms from the first read START to the last STOP matches the firmware figure.
- The DS3231 bytes decode to a valid time. In `measurement.csv` the seconds register reads `0x30`, `0x35`, `0x40` in the three cycles (23:28:30, 23:28:35, 23:28:40 on 05.10.2026), exactly 5 s apart. (The first read in `boot.csv`, `0x40 0x33 0x23 0x01 0x05 0x10 0x26`, is 23:33:40 on the same date.) The status register bit 7 (oscillator-stop flag) is 0.

## 3. SDA disconnected: failed attempts

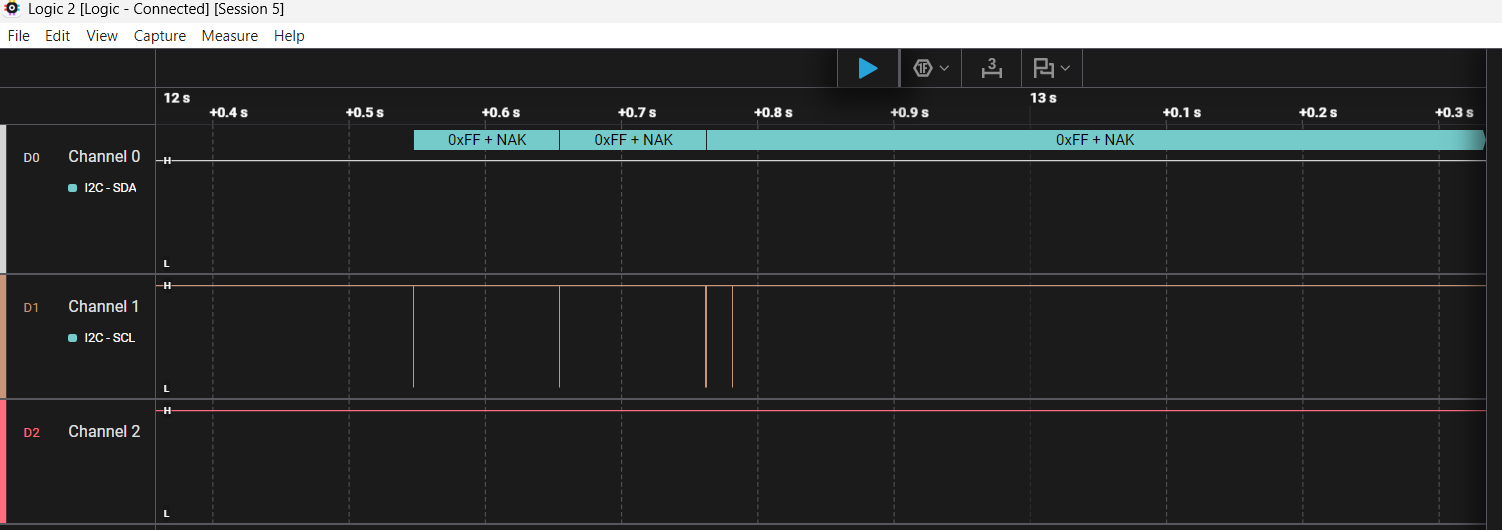
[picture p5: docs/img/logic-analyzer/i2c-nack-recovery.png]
Failed attempts


The SDA wire between the board and the modules was disconnected while the firmware was running; the analyzer's SDA probe stayed on the module side of the cut, so it sees SCL (driven by the board) but SDA never leaves the high level. With nothing pulling SDA low the decoder reads every frame as `0xFF + NAK`: no address is ever acknowledged. In `nack-recovery.csv`:

- the normal cycles at 2.547 s and 7.547 s decode as in section 2;
- the cycle at 12.547 s fails: three attempts at 12.547 s, 12.655 s and 12.762 s, **107.5 ms apart** (the 100 ms retry timer plus about 7.5 ms for the failing transfer), exactly the three attempts of the retry policy (`I2C_MAX_ATTEMPTS` = 3, `I2C_RETRY_DELAY_MS` = 100);
- the cycle at 17.547 s fails as well: the cycles at 12.5 s and 17.5 s are the two that are missing before the next valid one at 22.546 s, so the wire was out for two cycles;
- normal decoded traffic returns at 22.546 s.

The firmware log of a similar test ([`logs/phase4-i2c-recovery.txt`](logs/phase4-i2c-recovery.txt)) shows the same 3 attempts, the bus reset and the recovery.

In the screenshot a further short mark on SCL follows the third attempt after about 20 ms. That fits the clock pulses of the bus reset (`i2c_master_bus_reset()` clears a stuck bus with SCL pulses), but the decoder merges it into the last `0xFF + NAK` frame, so the capture does not let me confirm it pulse by pulse. The second failing cycle also shows one additional short frame about 4 ms before its first attempt that I cannot attribute to a specific firmware action.

## What this proves, and what it does not

It proves, on the real bus: the START / address / ACK / data / STOP structure of the traffic, NACK for the 109 unused addresses and ACK for the three devices, 400 kHz transfers, the 5 s cycle with the 10 ms conversion wait, and the retry spacing when the bus is broken. It does not show the individual SCL pulses of the bus reset.

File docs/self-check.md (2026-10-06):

# Self-check against the course checklist

The course checklist has 42 items. An item is ticked only when an artifact exists (code, log, measurement, document); items that do not fit this project are **not ticked** and carry a reason instead of being forced. The instructor said the 80 % threshold is not rigid and that adding a component only to cover an item would count as a weakness, so the "need" column says what the project itself requires, not which line it satisfies.

**Result: 30 of 42 ticked (71 %).** The four demonstration items (section 9) are ticked at the defence, after the live demo, which gives 34 of 42 (81 %). The remaining eight items are justified below.

## 1. Architecture

| # | Item | Done | Evidence | Need it covers |
|---|---|---|---|---|
| 1.1 | Superloop or RTOS | yes | FreeRTOS tasks T1-T4, `src/logic/sensor_task.cpp`, `src/transport/uart_log_task.cpp`; [`phase3-pipeline.txt`](logs/phase3-pipeline.txt) | Sensor, output, supervision and network are independent and wait differently; one fault must not stop the rest |
| 1.2 | No blocking `delay()` in the main logic | yes | no `delay`, `vTaskDelay` or busy-wait in `src/` and `include/` (waits are queue waits with timeouts and one-shot timers); [`defensive-review.md`](defensive-review.md) | An event-driven pause cannot hide a hang from the watchdog |
| 1.3 | State machine | yes | T1 FSM (Idle / WaitConversion / WaitRetry / Recovery); [`architecture.md`](architecture.md) section 4 | Conversion wait, retry and recovery are states, not blocking pauses |
| 1.4 | Architecture block diagram | yes | [`architecture.md`](architecture.md) section 10, README section 5 | Explain the system quickly |
| 1.5 | Logic split into modules | yes | `src/periph`, `src/logic`, `src/transport`, `src/reliability`, `include/config.h`; 37 unit tests on the PC | One driver can change without touching the rest |

## 2. Peripherals and interfaces

| # | Item | Done | Evidence | Need it covers |
|---|---|---|---|---|
| 2.1 | At least one analog subsystem (ADC / DAC / PWM / I2S / PDM) | **no** | The photoresistor was removed on 2026-09-29: a temperature, humidity and pressure logger has no need to measure light. Reason: [`decisions.md`](decisions.md) | Adding a sensor only for this item would make the design less coherent |
| 2.2 | At least one digital interface | yes | I2C with two devices on one bus, plus UART and Wi-Fi; [`phase2-bringup.txt`](logs/phase2-bringup.txt), [`logic-analyzer.md`](logic-analyzer.md) | BME280 and DS3231 share two wires |
| 2.3 | Interrupts | yes | Button ISR on GPIO6 posting to a queue with `xQueueSendFromISR`; `src/periph/button.cpp`; [`phase4-button.txt`](logs/phase4-button.txt) | Button gestures on demand: clear the error counter, trigger the watchdog test |
| 2.4 | Asynchronous data transfer (buffer / queue) | yes | T1 → `Q_LOG` → T2, T1 → `Q_MQTT` → T4; [`phase3-pipeline.txt`](logs/phase3-pipeline.txt) | The UART log does not depend on I2C timing or on the network |
| 2.5 | Timers or hardware events | yes | `esp_timer`: 5 s tick, 10 ms conversion, 100 ms retry, 2 s recovery, 3 s long press | Fixed 5 s period without drift; non-blocking waits |

## 3. RTOS

| # | Item | Done | Evidence | Need it covers |
|---|---|---|---|---|
| 3.1 | At least 2 tasks | yes | T1 sensor, T2 uart_log, T3 supervisor, T4 mqtt, diagnostics; [`architecture.md`](architecture.md) section 2 | Separation of responsibilities |
| 3.2 | Queue | yes | T1 queue, T3 queue, `Q_LOG`, `Q_MQTT`; overflow policy tested in [`phase6-queue-overflow.txt`](logs/phase6-queue-overflow.txt) | Task-to-task transfer without shared buffers |
| 3.3 | Mutex or other synchronization | yes | `I2cMutex` for the whole bus, 200 ms timeout, RAII guard; `src/reliability/i2c_mutex.cpp` | T1 (measurements) and T3 (bus reset) both reach the bus |
| 3.4 | No race conditions | yes | Review of every shared object in [`defensive-review.md`](defensive-review.md) section 4; 10 h run without a fault. There is no formal proof, only review and long runs | The logger runs for hours; a race would show up rarely and be hard to reproduce |

## 4. Control and algorithms

| # | Item | Done | Evidence | Need it covers |
|---|---|---|---|---|
| 4.1 | Feedback | yes | I2C error → 3 retries → bus reset by T3 → LED_ERR and `ERR` in the log; [`phase4-i2c-recovery.txt`](logs/phase4-i2c-recovery.txt) | The bus recovers on its own and the operator can see it |
| 4.2 | PID or another control algorithm | yes | EMA filter, `alpha` = 0.2, chosen with an experiment: [`ema-experiment.md`](ema-experiment.md), `include/ema.h`, `test/test_ema` | Smooth short disturbances and single outliers |
| 4.3 | Parameters can be configured | yes | All constants in `include/config.h` | Change interval, `alpha`, timeouts or pins in one place |
| 4.4 | Boundary conditions (overflow, saturation) | yes | Saturating `ErrorCounter`, sensor range and NaN checks, queue overflow policies; `include/error_counter.h`, `include/sensor_validation.h`, unit tests | The logger must not record a false value or wrap a counter |

## 5. Reliability

| # | Item | Done | Evidence | Need it covers |
|---|---|---|---|---|
| 5.1 | Watchdog | yes | Task WDT 10 s with panic, T1-T3 subscribed; triggered three times on purpose; `sdkconfig.defaults`, [`phase4-wdt.txt`](logs/phase4-wdt.txt) | A hung task must end in a restart, not in silence |
| 5.2 | Peripheral error handling | yes | Retries, bus reset, recovery; [`phase4-i2c-recovery.txt`](logs/phase4-i2c-recovery.txt), logic analyzer capture, [`defensive-review.md`](defensive-review.md) | A wire that comes loose |
| 5.3 | Invalid data is checked | yes | DS3231 validity (oscillator-stop flag, `2000-01-01`, field ranges) and `!TIME` / `!SENS` markers; [`phase3-rtc.txt`](logs/phase3-rtc.txt) | A dead RTC battery gives `2000-01-01`; a made-up time does more harm than a missing one |
| 5.4 | No hang on bad input | yes | SDA disconnected, a task hung on purpose, Wi-Fi lost; [`phase4-i2c-recovery.txt`](logs/phase4-i2c-recovery.txt), [`phase4-wdt.txt`](logs/phase4-wdt.txt), [`phase3-mqtt.txt`](logs/phase3-mqtt.txt) | Unattended operation |

## 6. Performance

| # | Item | Done | Evidence | Need it covers |
|---|---|---|---|---|
| 6.1 | Critical sections timed | yes | `esp_timer_get_time`: I2C start 534 µs, read 1230 µs, cycle 12 ms; confirmed on the wire; [`measurements.md`](measurements.md), [`logic-analyzer.md`](logic-analyzer.md) | Show the cycle fits into 5 s with a large margin |
| 6.2 | DMA (if appropriate) | **no, on purpose** | About 20 bytes of I2C per cycle, the bus is busy 0.035 % of the time, CPU 0.7 %; the time is driver overhead, not byte transfer ([`measurements.md`](measurements.md), "Is DMA appropriate?") | Measured: DMA would gain nothing here |
| 6.3 | No redundant data copies | yes | Only a 32-byte `LogEntry` is copied by value through queues once per 5 s; [`measurements.md`](measurements.md) | Confirm that passing by value costs nothing noticeable |
| 6.4 | CPU not overloaded (above 70 %) | yes | 0.5-0.8 % over a 10 h run (mean 0.63 %); [`phase7-long-run.txt`](logs/phase7-long-run.txt) | Headroom for the other tasks and the network |

## 7. PCB

| # | Item | Done | Evidence | Need it covers |
|---|---|---|---|---|
| 7.1 | Schematic | yes | `hardware/kicad/env-logger.kicad_sch`, exported to [`schematic/schematic.pdf`](schematic/schematic.pdf) and `schematic.png`. ERC (`kicad-cli` 10.0.4, `sch erc --severity-all`): 0 errors, 0 warnings. Four checks are switched off in the project settings (global label used once, four connection points joined, SPICE model, footprint filters) | Document the wiring of the modules and the pins |
| 7.2 | 2-layer PCB routed | **no** | Skipped on purpose: the logger is built from ready-made modules on a breadboard | A PCB is not needed to meet the project's goal |
| 7.3 | Power filtering | **no** | Same as 7.2; no custom board, so nothing to filter on it | n/a |
| 7.4 | Power and logic separated | **no** | Same as 7.2; one 3.3 V rail from the board | n/a |
| 7.5 | High-speed signal routing | **no** | Same as 7.2; the fastest signal is I2C at 400 kHz | n/a |
| 7.6 | Test points | **no** | Same as 7.2; SDA and SCL were probed with a logic analyzer on the breadboard | n/a |
| 7.7 | Board made and tested | **no** | Same as 7.2 | n/a |

## 8. Documentation

| # | Item | Done | Evidence | Need it covers |
|---|---|---|---|---|
| 8.1 | README with the task description | yes | [`README.md`](../README.md) section 1 | What, why, how to run, who made it, in 30 seconds |
| 8.2 | Block diagram | yes | README section 5, [`architecture.md`](architecture.md) sections 10-11 | A clear picture of the system without reading the code |
| 8.3 | Architecture description | yes | [`architecture.md`](architecture.md), [`decisions.md`](decisions.md) | Explain the choice of Task, Queue and Mutex |
| 8.4 | Run instructions | yes | README section 10 | Reproducible by someone else |
| 8.5 | Explanation of the interfaces | yes | README section 6, [`hardware.md`](hardware.md) | Show that the interface settings were chosen deliberately |

## 9. Demonstration

| # | Item | Done | Evidence | Need it covers |
|---|---|---|---|---|
| 9.1 | Runs stably for 5 minutes or more | at the defence | Prepared evidence: a 10 h 18 min run with no reset ([`phase7-long-run.txt`](logs/phase7-long-run.txt)) | |
| 9.2 | Boundary modes demonstrated | at the defence | Prepared: SDA disconnect, long press (watchdog), Wi-Fi loss | |
| 9.3 | Architecture explained | at the defence | | |
| 9.4 | PCB decision explained | at the defence | The PCB items are skipped on purpose (section 7) | |

## Not ticked, and why

- **2.1:** no analog quantity belongs in this logger; see the decision above.
- **6.2:** measured and found pointless, so the item is deliberately left unticked.
- **7.2-7.7:** the project uses ready-made modules; only the schematic (7.1) was made.
- **9.1-9.4:** these are ticked at the live demonstration, not before.

## What the checklist does not cover

The MQTT telemetry (T4) and the diagnostics task are extras; they are not counted in the items above, and the MQTT path is explicitly outside the I2C + WDT reliability guarantees (see README section 8).

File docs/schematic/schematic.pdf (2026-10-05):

1 | 2 | 3 | 4 | 5 | 6

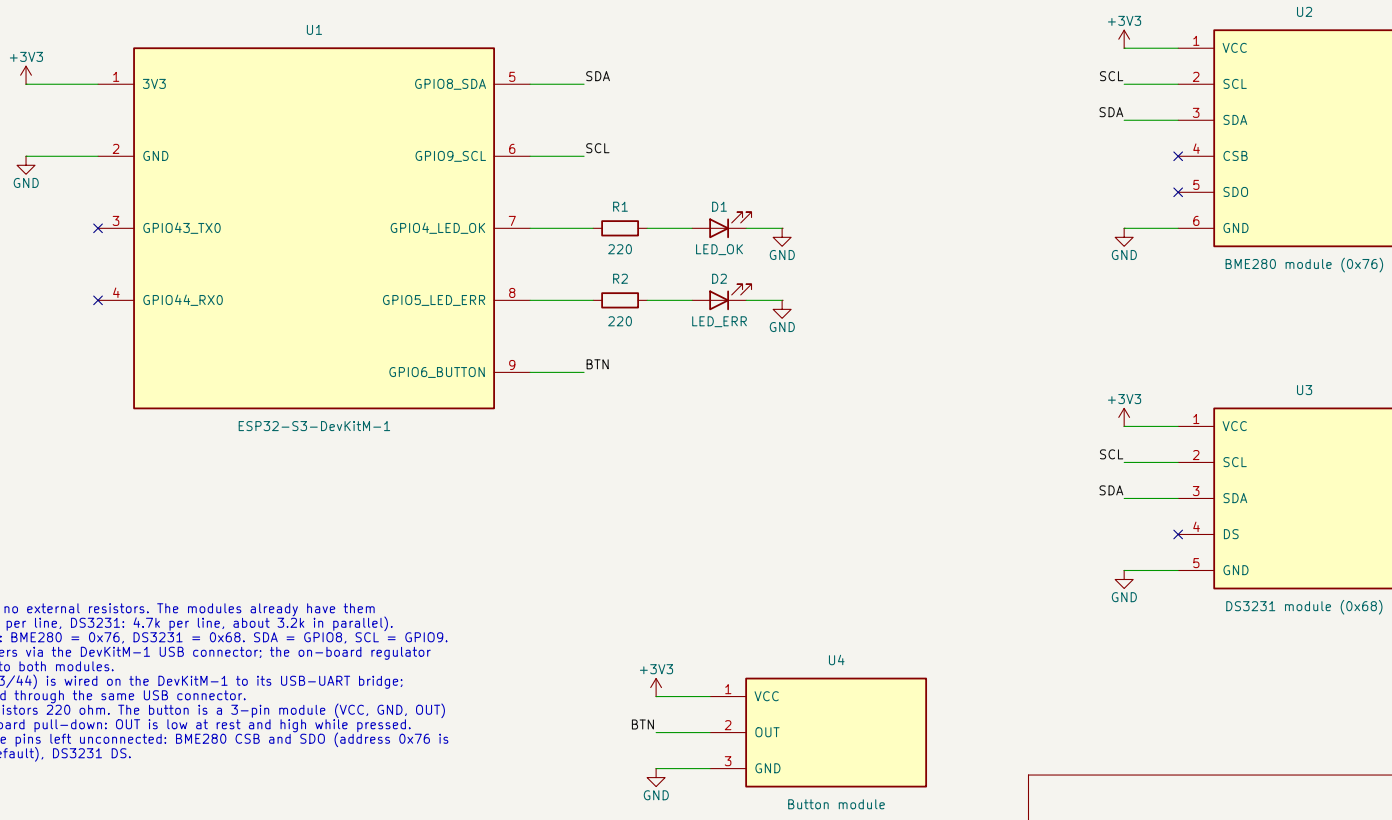
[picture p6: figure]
GND; VCC 1; SCL 2; SDA 3; CSB 4; SDO 5; GND 6; U2 BME280 module (0x76) R1; GND +3V3; +3V3 GND; OUT 2; GND 3; U4 Button module; GND 2; GPIO43_TX0 3; GPIO44_RX0 4; GPIO8_SDA; 5 GPIO9_SCL; 6 GPIO4_LED_OK; 7 GPIO5_LED_ERR; 8 GPIO6_BUTTON; ESP32-S3-DevKitM-1 GND; LED_OK +3V3; LED_ERR; 220 BTN; SCL SDA; SCL SDA SCL SDA BTN

1 | 2 | 3 | 4 | 5 | 6

AB

C

D

AB

C

### D Date: 2026-10-03

Size: A4 | Rev: 0.1
KiCad E.D.A. 10.0.4 | Id: 1/1

## Title: Environment Logger

File: env-logger.kicad_sch

### Sheet: /

SDA 3 | DS 4 | GND 5 | U3 DS3231 module (0x68) +3V3 D2

ESP32-S3-DevKitM-1 + BME280 + DS3231 on one I2C bus (400 kHz), 2 status LEDs, 1 button Notes 1. I2C pull-ups: no external resistors. The modules already have them

(BME280: 10k per line, DS3231: 4.7k per line, about 3.2k in parallel). 2. I2C addresses: BME280 = 0x76, DS3231 = 0x68. SDA = GPIO8, SCL = GPIO9. 3. Power: 5V enters via the DevKitM-1 USB connector; the on-board regulator

supplies 3V3 to both modules. 4. UART0 (GPIO43/44) is wired on the DevKitM-1 to its USB-UART bridge; the log is read through the same USB connector. 5. LED series resistors 220 ohm. The button is a 3-pin module (VCC, GND, OUT) with an on-board pull-down: OUT is low at rest and high while pressed. 6. Unused module pins left unconnected: BME280 CSB and SDO (address 0x76 is

# the module default), DS3231 DS. Environment Logger - schematic (module level)

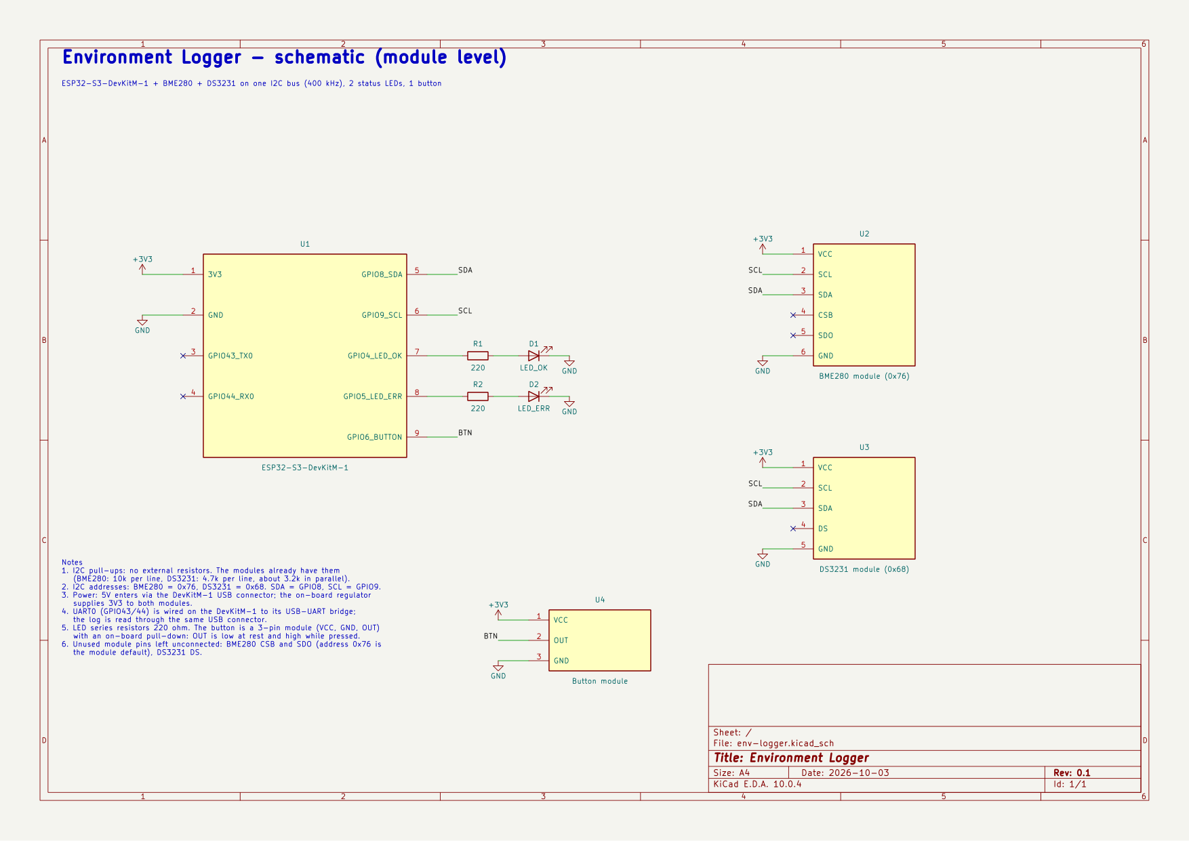
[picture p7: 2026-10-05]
docs/schematic/schematic.png

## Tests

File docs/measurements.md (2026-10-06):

# Measurements

All numbers come from the firmware's own diagnostics (`DiagnosticsTask`, and the timing log of T1) running on the real board, ESP32-S3-DevKitM-1, ESP-IDF 5.5.3, one measurement every 5 s. Raw logs: [`logs/phase6-diagnostics.txt`](logs/phase6-diagnostics.txt) and [`logs/phase6-queue-overflow.txt`](logs/phase6-queue-overflow.txt).

## Summary

| Quantity | Value | Where it comes from |
|---|---|---|
| Measurement cycle, tick to published entry | 11.9 / 12.0 / 12.4 ms (min / avg / max) | T1 timing, 12 cycles |
| ... of which waiting for the BME280 conversion | 10 ms (one-shot timer, the CPU is idle) | `config::BME280_CONVERSION_US` |
| I2C, start of a conversion (mutex wait + 2 register writes) | 529 / 534 / 540 us | T1 timing |
| I2C, read of BME280 and DS3231 (mutex wait + 4 transfers) | 1204 / 1230 / 1343 us | T1 timing |
| Time the I2C bus is busy per cycle | about 1.8 ms of 5000 ms (0.035 %) | sum of the two lines above |
| CPU load, both cores averaged | 0.7 % (target: below 70 %) | diagnostics, run-time counters |
| Free heap / lowest since boot | 234.9 KB / 226.9 KB after 10 h 18 min | diagnostics, [`phase7-long-run.txt`](logs/phase7-long-run.txt) |
| Number of tasks | 15 (4 application tasks, the rest are ESP-IDF system tasks) | diagnostics |

In the second run (fault injection test, 60 s after boot) the numbers were the same: start 521/523/528 us, read 1200/1225/1454 us, one cycle took up to 21.6 ms (a single outlier, probably Wi-Fi activity), CPU load 0.9 %.

## Stack usage (high-water mark)

Free stack is the smallest amount that was free since the task started, so used = size - free.

| Task | Stack size | Free (minimum) | Used | Verdict |
|---|---|---|---|---|
| T1_sensor | 4096 B | 1828 B | 2268 B | enough margin |
| T2_uart | 4096 B | 1876 B | 2220 B | enough margin |
| T3_supervisor | 4096 B | 3156 B | 940 B | could be 2048 B |
| T4_mqtt | 4096 B | 2000 B | 2096 B | enough margin |
| diag | 4096 B | 1760 B | 2336 B | enough margin |

The rule of thumb used here is to enlarge a stack that has less than 128 B free: none of the application tasks is close. The lowest margins in the system belong to ESP-IDF tasks that are not ours: `ipc0` (396 B free), `sys_evt` (576 B free; our Wi-Fi event handler runs in it) and `IDLE0`/`IDLE1` (740-812 B). They are above the threshold and stable, but `sys_evt` is the one to watch if more work is ever added to the Wi-Fi/MQTT callbacks.

## Long run

One uninterrupted capture of 10 h 18 min (37081 s of uptime), board on USB power, nobody touching it. Evidence: [`logs/phase7-long-run.txt`](logs/phase7-long-run.txt), produced from the raw capture by `tools/summarize_long_run.py`.

| Quantity | Value |
|---|---|
| Resets, watchdog, panic | none (one boot banner, reason power-on) |
| Log lines | 7425, all `ERR:0`, no `!SENS` or `!TIME` |
| Spacing of the lines (RTC seconds) | 5 s 7422 times, 6 s twice (03:52:27 and 08:01:53; the RTC has whole-second resolution, the cause was not investigated) |
| Free heap | 231.5-235.5 KB; lowest ever 230.6 KB at 60 s and 226.9 KB at the end, i.e. 3.7 KB lower. The minimum fell in seven small steps (at 60, 120, 300, 9616, 14003, 15325 and 33055 s) and the free heap itself came back each time (235.3 KB at 60 s, 234.9 KB at the end), so this looks like short transient dips, not a leak; the cause of the dips was not investigated |
| CPU load | 0.5-0.8 %, mean 0.63 % (617 snapshots) |
| Smallest free stack, T1 / T2 / T3 / T4 | 1796 / 1876 / 3156 / 2000 B |
| T1 cycle time over 618 reports | 11.9-13.5 ms |
| MQTT disconnects | 2 (10.3 s and 15.2 s), both reconnected by themselves; the UART log kept its 5 s lines meanwhile |

Free heap stayed inside a 4 KB band over the 617 minute-by-minute snapshots, with no downward trend.

## Is DMA appropriate?

No. One cycle moves about 20 bytes over I2C (BME280: 2 + 2 bytes written, 1 + 8 bytes read; DS3231: 1 + 7 + 1 + 1 bytes). The whole I2C phase takes 1.8 ms per 5 s and the CPU is busy 0.7 % of the time overall. DMA removes per-byte CPU work, but the measured time is dominated by per-transaction driver overhead, not by moving bytes, so DMA would save nothing measurable and add complexity. It would make sense for large buffers (for example a display frame buffer), which this project does not have. The checklist item "DMA (if appropriate)" is therefore not ticked, on purpose.

## Copies of data

The only data that moves between tasks is one `LogEntry` (about 32 bytes) per cycle:

- T1 builds it once and the queues copy it by value into Q_LOG (to T2) and Q_MQTT (to T4); each consumer reads it directly from the queue into a local variable;
- T2 formats it once into a 96-byte line buffer and prints it;
- T4 formats the numbers into a 24-byte payload buffer per topic.

A copy by value is what a FreeRTOS queue does, and it keeps the tasks independent (no shared buffer, no locking). At 32 bytes every 5 s this is negligible, so no redundant copies were removed.

## Queue overflow (fault injection)

With `config::FAULT_STALL_UART = true`, T2 stops reading Q_LOG for 90 s. The policy of Q_LOG is to drop the newest entry and count it:

- the queue (8 places) filled up and the first drop was logged at 60 s; ten entries were dropped in total;
- T1 was never blocked: the warnings arrived exactly every 5 s;
- when T2 resumed, it printed the oldest buffered entries first;
- the watchdog did not fire, because T2 kept feeding it.

Q_MQTT has the opposite policy (drop the oldest entry) so the broker always gets the freshest data.

## Cross-check with the logic analyzer

The timing measured by the firmware agrees with what the analyzer sees on the wire ([`logic-analyzer.md`](logic-analyzer.md)): the cycles start 4.99974 s apart, the BME280 conversion wait is 10.26 ms, the read phase from the first read START to the last STOP is 1.27 ms (firmware: 1.23 ms on average), and the data actually moving on the bus takes 0.63 ms per cycle. The difference between wire time and the firmware figures is driver and mutex overhead, not waiting on the devices.

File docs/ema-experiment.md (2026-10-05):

# EMA filter: why alpha = 0.2

The measurements are smoothed with an exponential moving average,
`filtered = alpha * raw + (1 - alpha) * filtered`, sampled every 5 s (`include/ema.h`, tested on the PC in `test/test_ema`).

## Time constant

For a sample period T the time constant is `tau = -T / ln(1 - alpha)`.

| alpha | tau at T = 5 s | meaning |
|---|---|---|
| 0.05 | 97 s | very slow |
| 0.2 | 22 s | follows a real change in about a minute |
| 0.5 | 7 s | almost no smoothing |

## Experiment

Real BME280 data, one sample every 5 s, all three filters fed with the same raw samples
(the experiment code that printed the CSV lines is in commit `57596bf`; it was removed when the measurement pipeline moved into tasks).
Data: [`data/ema_experiment.csv`](data/ema_experiment.csv). Plot script: `tools/plot_ema.py`.

The room was left alone for about 90 s, then a breath was directed at the sensor for roughly 45 s (a short, strong disturbance), then the sensor was left to recover.

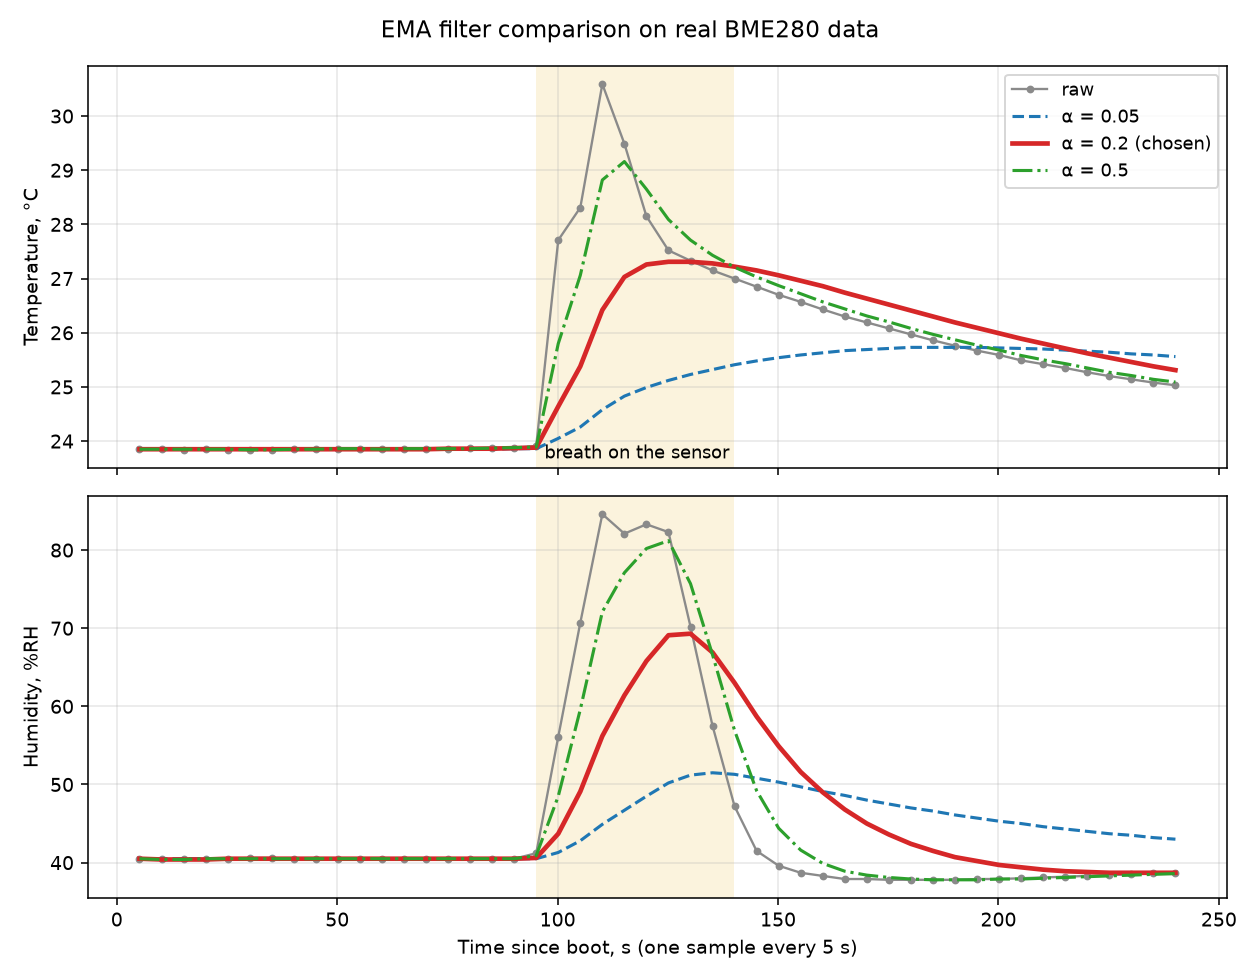
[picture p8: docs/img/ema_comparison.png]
EMA comparison


| | raw | alpha 0.05 | alpha 0.2 | alpha 0.5 |
|---|---|---|---|---|
| Temperature rise at the peak (baseline 23.9 C) | +6.7 C | +1.9 C (28 %) | +3.5 C (51 %) | +5.3 C (79 %) |
| Humidity rise at the peak (baseline 40.5 %RH) | +44.1 | +11.0 (25 %) | +28.8 (65 %) | +40.7 (92 %) |
| Temperature 130 s after the raw peak (raw 25.03 C) | 25.03 | 25.56 (+0.53) | 25.31 (+0.28) | 25.09 (+0.06) |
| Humidity 130 s after the raw peak (raw 38.7 %RH) | 38.7 | 43.0 (+4.3) | 38.7 (+0.0) | 38.6 (-0.1) |

## What the data shows

- **alpha = 0.5** reproduces 80-90 % of a short disturbance. It filters very little: a one-off outlier passes with 50 % of its size.
- **alpha = 0.05** reacts to only about a quarter of the disturbance and, more than two minutes later, still reports a humidity 4.3 %RH above the real value. For a logger it would publish stale numbers.
- **alpha = 0.2** is the compromise: it attenuates a short disturbance to roughly half or two thirds, is back on the raw value for humidity within about 100 s after the disturbance, and passes a single outlier with only 20 % of its size.

## Limits of this experiment

- In this room the sensor noise is tiny (raw temperature varies by about 0.04 C and humidity by 0.2 %RH while nothing happens), so noise suppression does not distinguish the alphas. The filter's practical value here is rejecting short disturbances and single bad samples.
- One run with a breath is not a standardised test, and the numbers will differ between runs.
- alpha is a trade-off between smoothing and lag, not a uniquely correct value: another application could reasonably choose 0.1 or 0.3. 0.2 is chosen because the lag of about a minute is acceptable for an environment logger with a 5 s period.

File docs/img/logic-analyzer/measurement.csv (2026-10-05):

name | type | start_time | duration | ack | address | read | data
I2C | start | 4.988108375 | 0.000000125
I2C | address | 4.988111 | 0.000021125 | true | 0x76 | false
I2C | data | 4.9881335 | 0.000021125 | true |  |  | 0xF2
I2C | data | 4.988156 | 0.000021125 | true |  |  | 0x01
I2C | stop | 4.988180375 | 0.000000125
I2C | start | 4.988249625 | 0.000000125
I2C | address | 4.98825225 | 0.000021125 | true | 0x76 | false
I2C | data | 4.98827475 | 0.000021125 | true |  |  | 0xF4
I2C | data | 4.98829725 | 0.000021125 | true |  |  | 0x25
I2C | stop | 4.988321625 | 0.000000125
I2C | start | 4.9985325 | 0.000000125
I2C | address | 4.998535125 | 0.000021125 | true | 0x76 | false
I2C | data | 4.998557625 | 0.000021125 | true |  |  | 0xF3
I2C | start | 4.998581875 | 0.000000125
I2C | address | 4.998584375 | 0.00002125 | true | 0x76 | true
I2C | data | 4.998606875 | 0.00002125 | false |  |  | 0x00
I2C | stop | 4.99863125 | 0.000000125
I2C | start | 4.99901775 | 0.000000125
I2C | address | 4.999020375 | 0.000021125 | true | 0x76 | false
I2C | data | 4.999042875 | 0.000021125 | true |  |  | 0xF7
I2C | start | 4.999067125 | 0.000000125
I2C | address | 4.999069625 | 0.00002125 | true | 0x76 | true
I2C | data | 4.999092125 | 0.00002125 | true |  |  | 0x54
I2C | data | 4.999114625 | 0.00002125 | true |  |  | 0x02
I2C | data | 4.999137125 | 0.00002125 | true |  |  | 0x00
I2C | data | 4.999159625 | 0.00002125 | true |  |  | 0x7D
I2C | data | 4.999182125 | 0.00002125 | true |  |  | 0x7F
I2C | data | 4.999204625 | 0.00002125 | true |  |  | 0x00
I2C | data | 4.999227125 | 0.00002125 | true |  |  | 0x63
I2C | data | 4.999249625 | 0.00002125 | false |  |  | 0xAD
I2C | stop | 4.999274 | 0.000000125
I2C | start | 4.999439625 | 0.000000125
I2C | address | 4.99944225 | 0.000021125 | true | 0x68 | false
I2C | data | 4.99946475 | 0.000021125 | true |  |  | 0x00
I2C | start | 4.999489 | 0.000000125
I2C | address | 4.9994915 | 0.000021125 | true | 0x68 | true
I2C | data | 4.999514 | 0.000021125 | true |  |  | 0x30
I2C | data | 4.9995365 | 0.000021125 | true |  |  | 0x28
I2C | data | 4.999559 | 0.000021125 | true |  |  | 0x23
I2C | data | 4.9995815 | 0.000021125 | true |  |  | 0x01
I2C | data | 4.999604 | 0.000021125 | true |  |  | 0x05
I2C | data | 4.9996265 | 0.000021125 | true |  |  | 0x10
I2C | data | 4.999649 | 0.000021125 | false |  |  | 0x26
I2C | stop | 4.999673375 | 0.000000125
I2C | start | 4.999756375 | 0.000000125
I2C | address | 4.999758875 | 0.00002125 | true | 0x68 | false
I2C | data | 4.999781375 | 0.00002125 | true |  |  | 0x0F
I2C | start | 4.999805625 | 0.000000125
I2C | address | 4.99980825 | 0.000021125 | true | 0x68 | true
I2C | data | 4.99983075 | 0.000021125 | false |  |  | 0x65
I2C | stop | 4.999855 | 0.000000125
I2C | start | 9.98784525 | 0.000000125
I2C | address | 9.987847875 | 0.000021125 | true | 0x76 | false
I2C | data | 9.987870375 | 0.000021125 | true |  |  | 0xF2
I2C | data | 9.987892875 | 0.000021125 | true |  |  | 0x01
I2C | stop | 9.98791725 | 0.000000125
I2C | start | 9.9879865 | 0.000000125
I2C | address | 9.987989125 | 0.000021125 | true | 0x76 | false
I2C | data | 9.988011625 | 0.000021125 | true |  |  | 0xF4
I2C | data | 9.988034125 | 0.000021125 | true |  |  | 0x25
I2C | stop | 9.9880585 | 0.000000125
I2C | start | 9.99827175 | 0.000000125
I2C | address | 9.99827425 | 0.00002125 | true | 0x76 | false
I2C | data | 9.99829675 | 0.00002125 | true |  |  | 0xF3
I2C | start | 9.998321 | 0.000000125
I2C | address | 9.998323625 | 0.000021125 | true | 0x76 | true
I2C | data | 9.998346125 | 0.000021125 | false |  |  | 0x00
I2C | stop | 9.9983705 | 0.000000125
I2C | start | 9.998474625 | 0.000000125
I2C | address | 9.99847725 | 0.000021125 | true | 0x76 | false
I2C | data | 9.99849975 | 0.000021125 | true |  |  | 0xF7
I2C | start | 9.998523875 | 0.000000125
I2C | address | 9.9985265 | 0.000021125 | true | 0x76 | true
I2C | data | 9.998549 | 0.000021125 | true |  |  | 0x54
I2C | data | 9.9985715 | 0.000021125 | true |  |  | 0x05
I2C | data | 9.998594 | 0.000021125 | true |  |  | 0x00
I2C | data | 9.9986165 | 0.000021125 | true |  |  | 0x7D
I2C | data | 9.998639 | 0.000021125 | true |  |  | 0x7D
I2C | data | 9.9986615 | 0.000021125 | true |  |  | 0x00
I2C | data | 9.998684 | 0.000021125 | true |  |  | 0x63
I2C | data | 9.9987065 | 0.000021125 | false |  |  | 0xAF
I2C | stop | 9.998730875 | 0.000000125
I2C | start | 9.99888725 | 0.000000125
I2C | address | 9.998889875 | 0.000021125 | true | 0x68 | false
I2C | data | 9.998912375 | 0.000021125 | true |  |  | 0x00
I2C | start | 9.9989365 | 0.000000125
I2C | address | 9.998939125 | 0.000021125 | true | 0x68 | true
I2C | data | 9.998961625 | 0.000021125 | true |  |  | 0x35
I2C | data | 9.998984125 | 0.000021125 | true |  |  | 0x28
I2C | data | 9.999006625 | 0.000021125 | true |  |  | 0x23
I2C | data | 9.999029125 | 0.000021125 | true |  |  | 0x01
I2C | data | 9.999051625 | 0.000021125 | true |  |  | 0x05
I2C | data | 9.999074125 | 0.000021125 | true |  |  | 0x10
I2C | data | 9.999096625 | 0.000021125 | false |  |  | 0x26
I2C | stop | 9.999121 | 0.000000125
I2C | start | 9.999203875 | 0.000000125
I2C | address | 9.9992065 | 0.000021125 | true | 0x68 | false
I2C | data | 9.999229 | 0.000021125 | true |  |  | 0x0F
I2C | start | 9.999253125 | 0.000000125
I2C | address | 9.99925575 | 0.000021125 | true | 0x68 | true
I2C | data | 9.99927825 | 0.000021125 | false |  |  | 0x65
I2C | stop | 9.999302625 | 0.000000125
I2C | start | 14.98758725 | 0.000000125
I2C | address | 14.987589875 | 0.000021125 | true | 0x76 | false
I2C | data | 14.987612375 | 0.000021125 | true |  |  | 0xF2
I2C | data | 14.987634875 | 0.000021125 | true |  |  | 0x01
I2C | stop | 14.98765925 | 0.000000125
I2C | start | 14.9877285 | 0.000000125
I2C | address | 14.987731125 | 0.000021125 | true | 0x76 | false
I2C | data | 14.987753625 | 0.000021125 | true |  |  | 0xF4
I2C | data | 14.987776125 | 0.000021125 | true |  |  | 0x25
I2C | stop | 14.9878005 | 0.000000125
I2C | start | 14.99801375 | 0.000000125
I2C | address | 14.998016375 | 0.000021125 | true | 0x76 | false
I2C | data | 14.998038875 | 0.000021125 | true |  |  | 0xF3
I2C | start | 14.998063 | 0.000000125
I2C | address | 14.998065625 | 0.000021125 | true | 0x76 | true
I2C | data | 14.998088125 | 0.000021125 | false |  |  | 0x00
I2C | stop | 14.9981125 | 0.000000125
I2C | start | 14.998216625 | 0.000000125
I2C | address | 14.99821925 | 0.000021125 | true | 0x76 | false
I2C | data | 14.99824175 | 0.000021125 | true |  |  | 0xF7
I2C | start | 14.998265875 | 0.000000125
I2C | address | 14.9982685 | 0.000021125 | true | 0x76 | true
I2C | data | 14.998291 | 0.000021125 | true |  |  | 0x54
I2C | data | 14.9983135 | 0.000021125 | true |  |  | 0x03
I2C | data | 14.998336 | 0.000021125 | true |  |  | 0x00
I2C | data | 14.9983585 | 0.000021125 | true |  |  | 0x7D
I2C | data | 14.998381 | 0.000021125 | true |  |  | 0x7D
I2C | data | 14.9984035 | 0.000021125 | true |  |  | 0x00
I2C | data | 14.998426 | 0.000021125 | true |  |  | 0x63
I2C | data | 14.9984485 | 0.000021125 | false |  |  | 0xAD
I2C | stop | 14.998472875 | 0.000000125
I2C | start | 14.99862925 | 0.000000125
I2C | address | 14.998631875 | 0.000021125 | true | 0x68 | false
I2C | data | 14.998654375 | 0.000021125 | true |  |  | 0x00
I2C | start | 14.9986785 | 0.000000125
I2C | address | 14.998681125 | 0.000021125 | true | 0x68 | true
I2C | data | 14.998703625 | 0.000021125 | true |  |  | 0x40
I2C | data | 14.998726125 | 0.000021125 | true |  |  | 0x28
I2C | data | 14.998748625 | 0.000021125 | true |  |  | 0x23
I2C | data | 14.998771125 | 0.000021125 | true |  |  | 0x01
I2C | data | 14.998793625 | 0.000021125 | true |  |  | 0x05
I2C | data | 14.998816125 | 0.000021125 | true |  |  | 0x10
I2C | data | 14.998838625 | 0.000021125 | false |  |  | 0x26
I2C | stop | 14.998863 | 0.000000125
I2C | start | 14.998945875 | 0.000000125
I2C | address | 14.9989485 | 0.000021125 | true | 0x68 | false
I2C | data | 14.998971 | 0.000021125 | true |  |  | 0x0F
I2C | start | 14.99899525 | 0.000000125
I2C | address | 14.99899775 | 0.00002125 | true | 0x68 | true
I2C | data | 14.99902025 | 0.00002125 | false |  |  | 0x65
I2C | stop | 14.999044625 | 0.000000125

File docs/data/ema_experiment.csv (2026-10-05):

uptime_ms | raw_t | t_a005 | t_a02 | t_a05 | raw_h | h_a005 | h_a02 | h_a05
5138 | 23.85 | 23.85 | 23.85 | 23.85 | 40.5 | 40.5 | 40.5 | 40.5
10138 | 23.85 | 23.85 | 23.85 | 23.85 | 40.4 | 40.5 | 40.4 | 40.4
15138 | 23.84 | 23.85 | 23.85 | 23.85 | 40.5 | 40.5 | 40.4 | 40.4
20138 | 23.86 | 23.85 | 23.85 | 23.85 | 40.5 | 40.5 | 40.4 | 40.5
25138 | 23.84 | 23.85 | 23.85 | 23.85 | 40.5 | 40.5 | 40.5 | 40.5
30138 | 23.84 | 23.85 | 23.85 | 23.84 | 40.6 | 40.5 | 40.5 | 40.5
35138 | 23.84 | 23.85 | 23.85 | 23.84 | 40.6 | 40.5 | 40.5 | 40.5
40138 | 23.86 | 23.85 | 23.85 | 23.85 | 40.5 | 40.5 | 40.5 | 40.5
45138 | 23.85 | 23.85 | 23.85 | 23.85 | 40.5 | 40.5 | 40.5 | 40.5
50138 | 23.86 | 23.85 | 23.85 | 23.86 | 40.5 | 40.5 | 40.5 | 40.5
55138 | 23.86 | 23.85 | 23.85 | 23.86 | 40.5 | 40.5 | 40.5 | 40.5
60138 | 23.85 | 23.85 | 23.85 | 23.85 | 40.5 | 40.5 | 40.5 | 40.5
65138 | 23.86 | 23.85 | 23.85 | 23.86 | 40.5 | 40.5 | 40.5 | 40.5
70138 | 23.86 | 23.85 | 23.85 | 23.86 | 40.5 | 40.5 | 40.5 | 40.5
75138 | 23.86 | 23.85 | 23.86 | 23.86 | 40.5 | 40.5 | 40.5 | 40.5
80138 | 23.87 | 23.85 | 23.86 | 23.86 | 40.5 | 40.5 | 40.5 | 40.5
85138 | 23.88 | 23.85 | 23.86 | 23.87 | 40.5 | 40.5 | 40.5 | 40.5
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

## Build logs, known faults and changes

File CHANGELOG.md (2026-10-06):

# Changelog

All notable changes to this project are recorded here. The format follows [Keep a Changelog](https://keepachangelog.com/en/1.1.0/) and the project uses [Semantic Versioning](https://semver.org/).

## [1.0.0] - 2026-10-06

First complete version: the logger measures, timestamps, logs over UART, publishes over MQTT and recovers from an I2C failure and from a hung task. Evidence for each item is in `docs/` ([self-check](docs/self-check.md)).

### Added

- **Measurement pipeline.**
  - BME280 driver (forced mode, calibration, compensation) and DS3231 driver (time read/set with validity classification) on one shared I2C bus at 400 kHz, using the new `driver/i2c_master.h`.
  - T1 sensor task, an event-driven state machine (Idle / WaitConversion / WaitRetry / Recovery) with one-shot timers instead of any `delay()`.
  - EMA filter (`alpha` = 0.2, chosen with an experiment, `docs/ema-experiment.md`), sensor plausibility check (range and NaN), and a `TimeSource` that falls back to the internal clock and marks the entry `!TIME` when the RTC is not valid.
  - Log line format `[HH:MM:SS] T:.. H:..% P:.. ERR:..` with `!TIME` and `!SENS` markers.
- **Four layers and tasks.** Periph, Logic, Transport/Output and Reliability layers; tasks T1 sensor, T2 uart_log (the only writer of log lines), T3 supervisor, T4 mqtt, and a diagnostics task. Queues between tasks with a documented overflow policy per queue, and one mutex (200 ms timeout, RAII guard) for the whole I2C bus.
- **I2C recovery.** Three attempts 100 ms apart, then a bus reset requested from T3 through `i2c_master_bus_reset()`, LED_ERR while it is handled, and a saturating error counter that a short button press clears.
- **Task watchdog.** 10 s timeout with panic on timeout, T1, T2 and T3 subscribed, fed from every timed queue wait; the reset reason is logged at boot (watchdog, panic and brownout are flagged). A long button press hangs T1 on purpose to demonstrate it.
- **Wi-Fi and MQTT telemetry (T4).** Best-effort publishing of `temp`, `hum`, `pres` and `err` to a public broker; five immediate reconnects, then one attempt every 30 s without a limit. The UART log does not depend on it.
- **Documentation.** README with block diagram, state machine and two sequence diagrams (normal cycle, I2C failure); architecture (adds a class view and a watchdog sequence diagram), decisions, hardware, defensive-coding review, measurements, logic analyzer captures, and a self-check against the course checklist (30 of 42 items, the rest justified or pending the live demo).
- **Hardware design.** KiCad schematic (module level, ERC with 0 errors and 0 warnings) exported to PDF and PNG.
- **Evidence.** Logs of every scenario in `docs/logs/`, including a 10 h 18 min run with no reset, `ERR:0` throughout and a flat heap; logic analyzer captures with a decoding script (`tools/analyze_i2c.py`); `tools/summarize_long_run.py` that produces the redacted long-run summary from a raw capture.
- **Unit tests** for the pure logic (`Ema`, `ErrorCounter`, `TimingStats`, sensor validation, log formatting): 37 tests, run on the PC with `pio test -e native`.

### Changed

- Course documents set both the watchdog timeout and the measurement interval to 5 s; here the watchdog feed is decoupled from the interval and the timeout is 10 s.
- The photoresistor from the original brief was removed (decision of 2026-09-29), so the log has no `LUX` field and checklist item 2.1 is not applicable.
- The button is a 3-pin module with a pull-down, pressed = high (the first schematic assumed an active-low switch); schematic, hardware doc and `BUTTON_PRESSED_LEVEL` were updated to match the build.

### Fixed

- `FAULT_STALL_UART` (the fault injection that stops the UART task for 90 s) was committed as `true`; it is now `false`, so a fresh build logs normally.
- Button: a release bounce no longer produces a second press (quiet-time debounce on both edges); a failed `init()` of the BME280 or DS3231 now releases its I2C device handle.

### Known limitations

- The MQTT broker is public and unauthenticated, and delivery is QoS 0.
- A button tap shorter than the 50 ms debounce loses its release event.
- Light Sleep was deliberately not implemented (USB power, conflicts with the Wi-Fi link and the UART log); DMA was measured and found pointless; no PCB was made.
- A non-rechargeable CR2032 is fitted in a DS3231 module with a charging circuit: fine for a short demo, not for long unattended use.

Full list: README section 13.

[1.0.0]: https://github.com/yuriyKazan/Environment-logger/releases/tag/v1.0.0

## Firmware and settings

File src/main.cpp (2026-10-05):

#include "esp_log.h"
#include "esp_system.h"

#include <cstdlib>
#include <cstring>
#include <ctime>

#include "bme280.h"
#include "button.h"
#include "config.h"
#include "data_types.h"
#include "ds3231.h"
#include "esp_timer.h"
#include "nvs_flash.h"
#include "reset_reason.h"
#include "freertos/FreeRTOS.h"
#include "freertos/queue.h"
#include "i2c_bus.h"
#include "i2c_mutex.h"
#include "led.h"
#include "mqtt_publisher.h"
#include "mqtt_task.h"
#include "diagnostics_task.h"
#include "error_counter.h"
#include "sensor_task.h"
#include "supervisor_task.h"
#include "time_source.h"
#include "uart_log_task.h"
#include "wifi_manager.h"

static const char *TAG = config::APP_NAME;

static I2cBus g_i2c;
static I2cMutex g_i2c_mutex;
static Led g_led_ok(config::LED_OK_GPIO);
static Led g_led_err(config::LED_ERR_GPIO);
static Bme280 g_bme(g_i2c, config::I2C_ADDR_BME280);
static Ds3231 g_rtc(g_i2c, config::I2C_ADDR_DS3231);
static TimeSource g_time;
static Button g_button(config::BUTTON_GPIO);
static ErrorCounter g_errors;
static QueueHandle_t g_log_queue;   // Q_LOG: T1 -> T2
static QueueHandle_t g_err_queue;   // T3's queue: errors from T1 and button events
static QueueHandle_t g_mqtt_queue;  // Q_MQTT: T1 -> T4
static WifiManager g_wifi;
static MqttPublisher g_mqtt;
static MqttTask *g_mqtt_task;  // needs Q_MQTT, created in app_main
static SensorTask g_sensor_task(g_i2c_mutex, g_bme, g_rtc, g_time, g_errors);
static SupervisorTask g_supervisor(g_i2c, g_i2c_mutex, g_led_ok, g_led_err, g_button, g_errors);
static DiagnosticsTask g_diagnostics;
static UartLogTask *g_uart_task;  // needs Q_LOG, created in app_main

static const char *device_name(uint8_t addr)
{
    switch (addr) {
    case config::I2C_ADDR_BME280: return "BME280";
    case config::I2C_ADDR_DS3231: return "DS3231";
    case config::I2C_ADDR_AT24C32: return "AT24C32 EEPROM on DS3231 module";
    default:                      return "unknown";
    }
}

static bool was_found(const uint8_t *found, size_t n, uint8_t addr)
{
    for (size_t i = 0; i < n; i++) {
        if (found[i] == addr) {
            return true;
        }
    }
    return false;
}

// Parse __DATE__ ("Oct  5 2026") and __TIME__ ("11:42:51") of this build.
static bool build_time(Ds3231Time &t)
{
    static const char *months = "JanFebMarAprMayJunJulAugSepOctNovDec";
    const char *date = __DATE__;
    const char *found = nullptr;
    for (int i = 0; i < 12; i++) {
        if (strncmp(date, months + 3 * i, 3) == 0) {
            t.month = (uint8_t)(i + 1);
            found = date;
        }
    }
    if (found == nullptr) {
        return false;
    }
    t.day = (uint8_t)atoi(date + 4);
    t.year = (uint16_t)atoi(date + 7);
    const char *tm_str = __TIME__;
    t.hour = (uint8_t)atoi(tm_str);
    t.minute = (uint8_t)atoi(tm_str + 3);
    t.second = (uint8_t)atoi(tm_str + 6);
    return true;
}

// Boot self-check (I2C scan, register reads), then start the tasks.
extern "C" void app_main(void)
{
    ESP_LOGI(TAG, "boot, IDF %s", esp_get_idf_version());
    log_reset_reason();

    if (g_i2c.init() != ESP_OK) {
        ESP_LOGE(TAG, "I2C bus init failed");
        return;
    }

    uint8_t found[config::I2C_SCAN_MAX_FOUND];
    size_t count = 0;
    if (g_i2c.scan(found, config::I2C_SCAN_MAX_FOUND, &count) != ESP_OK) {
        ESP_LOGE(TAG, "I2C scan failed");
        return;
    }
    const size_t shown = count < config::I2C_SCAN_MAX_FOUND ? count : config::I2C_SCAN_MAX_FOUND;
    ESP_LOGI(TAG, "I2C scan (probe @ 100 kHz): %u device(s)", (unsigned)count);
    for (size_t i = 0; i < shown; i++) {
        ESP_LOGI(TAG, "  0x%02X (%s)", found[i], device_name(found[i]));
    }
    const uint8_t expected[] = {config::I2C_ADDR_BME280, config::I2C_ADDR_DS3231};
    for (uint8_t addr : expected) {
        if (!was_found(found, shown, addr)) {
            ESP_LOGE(TAG, "0x%02X %s: NOT FOUND (check wiring/power)", addr, device_name(addr));
            return;
        }
    }

    // Devices, RTC state and time source. The tasks are not running yet, so no mutex is needed here.
    if (g_bme.init() != ESP_OK || g_rtc.init() != ESP_OK) {
        ESP_LOGE(TAG, "BME280/DS3231 init failed");
        return;
    }
    Ds3231Reading rtc;
    if (g_rtc.read(rtc) == ESP_OK) {
        ESP_LOGI(TAG, "RTC %04u-%02u-%02u %02u:%02u:%02u: %s", rtc.time.year, rtc.time.month, rtc.time.day,
                 rtc.time.hour, rtc.time.minute, rtc.time.second, rtc_status_name(rtc.status));
        Ds3231Time bt;
        if (config::RTC_SET_FROM_BUILD_TIME_IF_INVALID && rtc.status != RtcStatus::Valid && build_time(bt)) {
            ESP_LOGW(TAG, "setting RTC from build time");
            if (g_rtc.set_time(bt) != ESP_OK) {
                ESP_LOGE(TAG, "RTC set_time failed");
            }
        }
    } else {
        ESP_LOGE(TAG, "RTC read failed");
    }
    g_time.init(g_rtc);

    // Synchronisation objects, then the tasks (T1 sensor, T2 UART log) and the button.
    g_log_queue = xQueueCreate(config::LOG_QUEUE_LEN, sizeof(LogEntry));
    g_mqtt_queue = xQueueCreate(config::MQTT_QUEUE_LEN, sizeof(LogEntry));
    g_err_queue = xQueueCreate(config::ERR_QUEUE_LEN, sizeof(IsrEvent));
    g_uart_task = new UartLogTask(g_log_queue);
    g_mqtt_task = new MqttTask(g_mqtt, g_mqtt_queue);
    if (g_i2c_mutex.init() != ESP_OK || g_log_queue == nullptr || g_mqtt_queue == nullptr || g_err_queue == nullptr ||
        g_led_ok.init() != ESP_OK || g_led_err.init() != ESP_OK) {
        ESP_LOGE(TAG, "mutex/queue/LED init failed");
        return;
    }
    if (g_uart_task->start() != ESP_OK || g_sensor_task.start(g_log_queue, g_mqtt_queue, g_err_queue) != ESP_OK ||
        g_supervisor.start(g_err_queue, g_sensor_task.queue()) != ESP_OK ||
        g_button.init(g_err_queue) != ESP_OK) {
        ESP_LOGE(TAG, "task or button start failed");
        return;
    }

    if (config::DIAG_ENABLED && g_diagnostics.start() != ESP_OK) {
        ESP_LOGW(TAG, "diagnostics task not started");  // not essential: the logger runs without it
    }

    // Network last and best effort: if anything fails here, the UART log keeps running.
    esp_err_t nvs = nvs_flash_init();
    if (nvs == ESP_ERR_NVS_NO_FREE_PAGES || nvs == ESP_ERR_NVS_NEW_VERSION_FOUND) {
        if (nvs_flash_erase() == ESP_OK) {
            nvs = nvs_flash_init();
        }
    }
    if (nvs != ESP_OK || g_mqtt.init() != ESP_OK || g_mqtt_task->start() != ESP_OK ||
        g_wifi.init(&MqttPublisher::on_wifi_connected, &g_mqtt) != ESP_OK) {
        ESP_LOGE(TAG, "Wi-Fi/MQTT start failed: continuing with the UART log only");
    }

    ESP_LOGI(TAG, "running: one log line every %u ms", (unsigned)config::MEASURE_INTERVAL_MS);
}

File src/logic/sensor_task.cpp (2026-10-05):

#include "sensor_task.h"

#include "config.h"
#include "esp_log.h"
#include "freertos/semphr.h"
#include "freertos/task.h"
#include "sensor_validation.h"
#include "watchdog.h"

static const char *TAG = "T1";

SensorTask::SensorTask(I2cMutex &i2c_mutex, Bme280 &bme, Ds3231 &rtc, TimeSource &time_source, ErrorCounter &errors)
    : i2c_mutex_(i2c_mutex),
      bme_(bme),
      rtc_(rtc),
      time_(time_source),
      errors_(errors),
      ema_t_(config::EMA_ALPHA),
      ema_h_(config::EMA_ALPHA),
      ema_p_(config::EMA_ALPHA)
{
}

esp_err_t SensorTask::start(QueueHandle_t log_queue, QueueHandle_t mqtt_queue, QueueHandle_t supervisor_queue)
{
    if (queue_ != nullptr || log_queue == nullptr || mqtt_queue == nullptr || supervisor_queue == nullptr) {
        return ESP_ERR_INVALID_STATE;
    }
    log_queue_ = log_queue;
    mqtt_queue_ = mqtt_queue;
    supervisor_queue_ = supervisor_queue;
    queue_ = xQueueCreate(config::ISR_QUEUE_LEN, sizeof(IsrEvent));
    if (queue_ == nullptr) {
        return ESP_ERR_NO_MEM;
    }

    struct TimerSpec {
        esp_timer_handle_t *handle;
        esp_timer_cb_t cb;
        const char *name;
    };
    const TimerSpec specs[] = {
        {&tick_timer_, &SensorTask::tick_cb, "tick"},
        {&conv_timer_, &SensorTask::conversion_cb, "bme_conv"},
        {&retry_timer_, &SensorTask::retry_cb, "i2c_retry"},
        {&recovery_timer_, &SensorTask::recovery_timeout_cb, "recovery_to"},
    };
    for (const TimerSpec &spec : specs) {
        esp_timer_create_args_t args = {};
        args.callback = spec.cb;
        args.arg = this;
        args.name = spec.name;
        const esp_err_t err = esp_timer_create(&args, spec.handle);
        if (err != ESP_OK) {
            return err;
        }
    }

    if (xTaskCreate(&SensorTask::task_entry, "T1_sensor", config::SENSOR_TASK_STACK, this, config::SENSOR_TASK_PRIO,
                    nullptr) != pdPASS) {
        return ESP_ERR_NO_MEM;
    }
    return esp_timer_start_periodic(tick_timer_, (uint64_t)config::MEASURE_INTERVAL_MS * 1000);
}

void SensorTask::task_entry(void *arg)
{
    static_cast<SensorTask *>(arg)->run();
}

// esp_timer callbacks only post events; all work happens in the task.
void SensorTask::tick_cb(void *arg) { static_cast<SensorTask *>(arg)->post(IsrEventType::Tick); }
void SensorTask::conversion_cb(void *arg) { static_cast<SensorTask *>(arg)->post(IsrEventType::ConversionDone); }
void SensorTask::retry_cb(void *arg) { static_cast<SensorTask *>(arg)->post(IsrEventType::Retry); }
void SensorTask::recovery_timeout_cb(void *arg) { static_cast<SensorTask *>(arg)->post(IsrEventType::RecoveryTimeout); }

void SensorTask::post(IsrEventType type)
{
    const IsrEvent ev = {type, esp_timer_get_time(), 0};
    if (xQueueSend(queue_, &ev, 0) != pdTRUE) {
        dropped_events_++;  // a timer event is lost only if T1 is badly behind; the next tick starts over
        ESP_LOGW(TAG, "event queue full, timer event dropped (total %u)", (unsigned)dropped_events_);
    }
}

void SensorTask::notify_supervisor(IsrEventType type, int32_t value)
{
    const IsrEvent ev = {type, esp_timer_get_time(), value};
    if (xQueueSend(supervisor_queue_, &ev, 0) != pdTRUE) {
        ESP_LOGW(TAG, "supervisor queue full, event dropped");
    }
}

void SensorTask::run()
{
    wdt_subscribe_current_task("T1");
    for (;;) {
        IsrEvent ev;
        // Finite wait, so the loop (and the watchdog feed) runs at least once per TASK_WAIT_MS.
        const bool got_event = xQueueReceive(queue_, &ev, pdMS_TO_TICKS(config::TASK_WAIT_MS)) == pdTRUE;
        wdt_feed();
        if (!got_event) {
            continue;
        }
        switch (ev.type) {
        case IsrEventType::Tick:            on_tick(); break;
        case IsrEventType::ConversionDone:  on_conversion_done(); break;
        case IsrEventType::Retry:           on_retry(); break;
        case IsrEventType::RecoveryDone:    on_recovery_done(ev); break;
        case IsrEventType::RecoveryTimeout: on_recovery_timeout(); break;
        case IsrEventType::TestHang:        test_hang(); break;
        default:                            break;  // events meant for T3
        }
    }
}

void SensorTask::on_tick()
{
    if (state_ != State::Idle) {
        ESP_LOGW(TAG, "tick while the previous cycle is still running: skipped");
        return;
    }
    attempt_ = 0;
    cycle_start_us_ = esp_timer_get_time();
    begin_attempt();
}

void SensorTask::begin_attempt()
{
    attempt_++;
    esp_err_t err;
    const int64_t t0 = esp_timer_get_time();
    {
        I2cLockGuard lock(i2c_mutex_, config::I2C_MUTEX_TIMEOUT_MS);
        err = lock.locked() ? bme_.start_measurement() : ESP_ERR_TIMEOUT;
    }
    if (err == ESP_OK) {
        start_stats_.add((uint32_t)(esp_timer_get_time() - t0));
    }
    if (err != ESP_OK) {
        attempt_failed(err, "BME280 start");
        return;
    }
    // Wait for the conversion with a one-shot timer instead of a delay.
    err = esp_timer_start_once(conv_timer_, config::BME280_CONVERSION_US);
    if (err != ESP_OK) {
        attempt_failed(err, "conversion timer");
        return;
    }
    state_ = State::WaitConversion;
}
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

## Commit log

2026-10-02 Pin espressif32 6.13.0 (ESP-IDF 5.5.3) and monitor settings
2026-10-02 Add hardware doc: peripherals, GPIO map, wiring
2026-10-03 Hardware doc: I2C pull-ups are on the modules, add RTC battery note
2026-10-03 Hardware doc: shorten RTC battery note
2026-10-03 Ignore KiCad backup and local files
2026-10-03 Add KiCad schematic (module level) with project symbol library
    [env-logger.kicad_sch]
2026-10-03 Export schematic to PDF/PNG and link it from hardware doc
2026-10-03 Ignore KiCad history and lock files
2026-10-03 Resave KiCad project in KiCad 10 format
    [env-logger.kicad_sch]
2026-10-03 Schematic: add unused module pins (BME280 CSB/SDO, DS3231 DS), fix label overlaps
    [env-logger.kicad_sch]
2026-10-04 Add I2cBus (periph): shared master bus, probe, scan, register read
2026-10-04 Switch to C++ and add I2C scanner with 400 kHz register reads in app_main
2026-10-05 Name the AT24C32 EEPROM (0x50) in the I2C scan output
2026-10-05 Add LED/button/queue constants and IsrEvent type
2026-10-05 Add Led (periph)
2026-10-05 Add Button (periph): falling-edge ISR, time-window debounce, event to queue
2026-10-05 Bring-up: LED_OK heartbeat timer and button event task
2026-10-05 Button: quiet-time debounce on both edges to ignore release bounce
2026-10-05 Add Bme280 driver (periph): forced mode, esp_err_t, calibration, compensation
2026-10-05 Bring-up: periodic BME280 measurement via one-shot conversion timer
2026-10-05 Add Ds3231 driver (periph): time read/set with validity classification
2026-10-05 Add Ema filter (logic) with native Unity tests
2026-10-05 Bring-up: EMA-filtered output and alpha comparison CSV experiment
2026-10-05 Add EMA alpha experiment: data, plot script, plot and write-up
    [ema_experiment.csv]
2026-10-05 Add I2cMutex and RAII I2cLockGuard (reliability): one mutex for the whole bus, finite timeout
2026-10-05 Add SensorTask (T1): event-driven measurement FSM, EMA, LogEntry to Q_LOG
2026-10-05 Add UartLogTask (T2): single owner of UART log lines
2026-10-05 main: boot self-check, then start T1/T2 and the button; drop the bring-up task
2026-10-05 Add WifiManager (periph): event-driven station, fast retries then a slow one-shot retry timer
2026-10-05 Phase 3.7 log: add the router outage capture (UART unaffected)
2026-10-05 Log the reset reason at boot (watchdog, panic, brownout are flagged)
    [main.cpp]
2026-10-05 I2cBus::reset(): hardware reset and bus clear via i2c_master_bus_reset
    [i2c_bus.cpp]
2026-10-05 Button: report releases too and expose is_pressed()
2026-10-05 T1: retry x3 with one-shot timers, then request a bus reset and log the failed cycle
    [sensor_task.cpp]
2026-10-05 Add SupervisorTask (T3): bus reset, LEDs, button gestures; wire it into main
    [main.cpp, supervisor_task.cpp]
2026-10-05 T3: subscribe to the task watchdog; log button events for diagnosis
2026-10-05 Button: configurable pressed level (this build is active high); clearer button diagnostics
2026-10-05 Add Phase 4 logs: I2C failure recovery and the watchdog test
2026-10-05 Schematic: the button is a 3-pin module (VCC, GND, OUT) with a pull-down, pressed = high
    [env-logger.kicad_sch]
2026-10-05 Hardware doc: button module wiring and polarity
2026-10-05 Add Phase 4.2 button gesture log
2026-10-05 Add sensor sample plausibility check with native tests
2026-10-05 T1: reject implausible BME280 samples before the filter (counted as a failed attempt)
    [sensor_task.cpp]
2026-10-05 Defensive review: check ignored return values, atomic connection flags, button diagnostics at debug level
2026-10-05 BME280/DS3231: a failed init releases the I2C device handle
    [bme280.cpp, ds3231.cpp]
2026-10-05 T1: measure and log the timing of the I2C phases and the whole cycle
2026-10-05 Add the measurements document (timing, CPU, stack, heap, DMA, copies, overflow)
2026-10-05 Logic analyzer: decoded captures and CSV exports, analysis script, corrected timing interpretation
    [boot.csv, measurement.csv, nack-recovery.csv]
2026-10-05 Add README, disable the UART stall fault injection, drop the current-consumption note
2026-10-06 Self-check: record the KiCad ERC result
2026-10-06 README: wrap lines, document the CR2032 battery and its charging-circuit caveat
2026-10-06 Docs review pass: fix the FSM diagram, document the boot self-check limitation, log levels and stack data, correct the RTC battery and the copyright holder
